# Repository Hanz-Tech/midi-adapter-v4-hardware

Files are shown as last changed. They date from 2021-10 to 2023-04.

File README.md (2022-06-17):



Buy it Here 

<a href="https://hanztechnology.com/shop">https://hanztechnology.com/shop</a>

OR



# Disclaimer

You are free to:

Share — copy and redistribute the material in any medium or format

Adapt — remix, transform, and build upon the material

________________________________________

Attribution — You must give appropriate credit, provide a link to the license, and indicate if changes were made. You may do so in any reasonable manner, but not in any way that suggests the licensor endorses you or your use.

NonCommercial — You may not use the material for commercial purposes.

___________________________________________

THE HARDWARE IS PROVIDED "AS IS", WITHOUT WARRANTY OF ANY KIND, EXPRESS OR IMPLIED, INCLUDING BUT NOT LIMITED TO THE WARRANTIES OF MERCHANTABILITY, FITNESS FOR A PARTICULAR PURPOSE AND NONINFRINGEMENT. IN NO EVENT SHALL THE AUTHORS OR COPYRIGHT HOLDERS BE LIABLE FOR ANY CLAIM, DAMAGES OR OTHER LIABILITY, WHETHER IN AN ACTION OF CONTRACT, TORT OR OTHERWISE, ARISING FROM, OUT OF OR IN CONNECTION WITH THE HARDWARE OR THE USE OR OTHER DEALINGS IN THE HARDWARE.

_____________________________________________

# Overview

This repo contains both the CAD for the 3D printed cover for the Pocket Operator and the PCB schematic for the adapter. PCB is created using KiCad. Software can be found [here](https://github.com/PO-MIDI-Adapter/midi-adapter-software/tree/v2)

## For assmebly instruction please go to the [wiki](https://github.com/PO-MIDI-Adapter/midi-adapter-hardware/wiki)

PO-MA (https://www.youtube.com/watch?v=n_peiBfl6JI "PO-MA")

# Photos

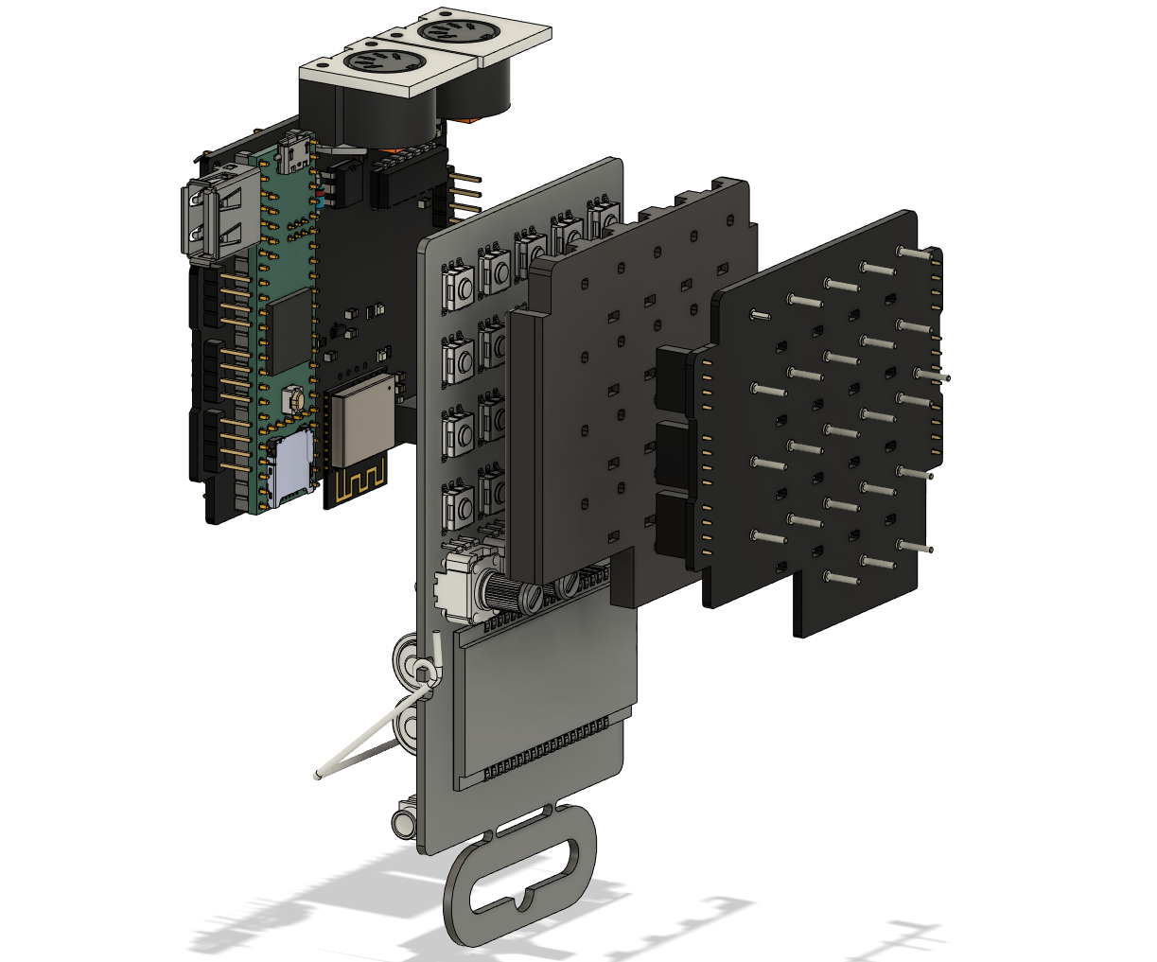
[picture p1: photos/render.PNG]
Render







# BOM
<!-- 
1. 1 x PCB board
2. 1 x 3D printed cover (Found in the cad folder)
3. 2 x cover holders  (Found in the cad folder)
4. 25 x pogo pins [ebay](https://www.ebay.ca/itm/100pcs-9mm-Length-Spring-Loaded-Test-Probes-Pogo-Pins-Cusp-Spear-for-Testing/163156710143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)
5. 1 x PJ320B 3.5MM Audio Jack (ebay)

In addition, you would need the following electronics from Digikey (bom.csv)

|Manufacturer Part Number|Manufacturer |Digi-Key Part Number|Quantity|Description |Placement|
|---|---|---|---|---|---|
|SN74HC125N |Texas Instruments |296-1572-5-ND |1 |IC BUFFER NON-INVERT 6V 14DIP |U2
|A 14-LC-TT |Assmann WSW Components |AE9989-ND |1 |CONN IC DIP SOCKET 14POS TIN |U2
|1-2199298-1 |TE Connectivity |A120346-ND |1 |CONN IC DIP SOCKET 6POS TIN |U3
|H11L1M |ON Semiconductors |H11L1-MQT-ND |1 |OPTOISO 4.17KV OPN COLL 6DIP |U3
|PRPC028SACN-RC |Sullins Connector Solutions|S1131EC-28-ND |2 |CONN HEADER VERT 28POS 2.54MM |U1
|DEV-16771 |SparkFun Electronics |1568-DEV-16771-ND |1 |TEENSY 4.1 W/OUT HDRS K66 EVAL  |U1
|SDS-50J |CUI Inc. |CP-2350-ND |2 |CONN RCPT FMALE DIN 5POS SOLDER |J29,J30
|CF14JT220R |Stackpole Electronics Inc  |CF14JT220RCT-ND |3 |RES 220 OHM 1/4W 5% AXIAL |R2,R3,R7
|CF14JT10K0 |Stackpole Electronics Inc  |CF14JT10K0CT-ND |1 |RES 10K OHM 1/4W 5% AXIAL |R4
|CF14JT470R |Stackpole Electronics Inc  |CF14JT470RTR-ND |1 |RES 470 OHM 1/4W 5% AXIAL |R8
|USB-A1HSW6 |On Shore Technology Incs |ED2989-ND |1 |USB-A Receptacle Connector 4 Pos|J19
|C315C104M5U5TA7303 |KEMET |399-9859-1-ND |2 |CAP CER 0.1UF 50V Z5U RADIAL |C2,C1
|PPTC041LFBN-RC |Sullins Connector Solutions|S7002-ND |1 |CONN HDR 4POS 0.1 TIN PCB |J32
|1N914 |ON Semiconductor |1N914FS-ND |1 |DIODE GEN PURP 100V 200MA DO35  |D1

Optional

|Manufacturer Part Number|Manufacturer |Digi-Key Part Number|Quantity  |Description |Placement|
|---|---|---|---|---|---|
|PPTC241LFBN-RC |Sullins Connector Solutions|S7022-ND |2 |CONN HDR 24POS 0.1 TIN PCB |U1 -->

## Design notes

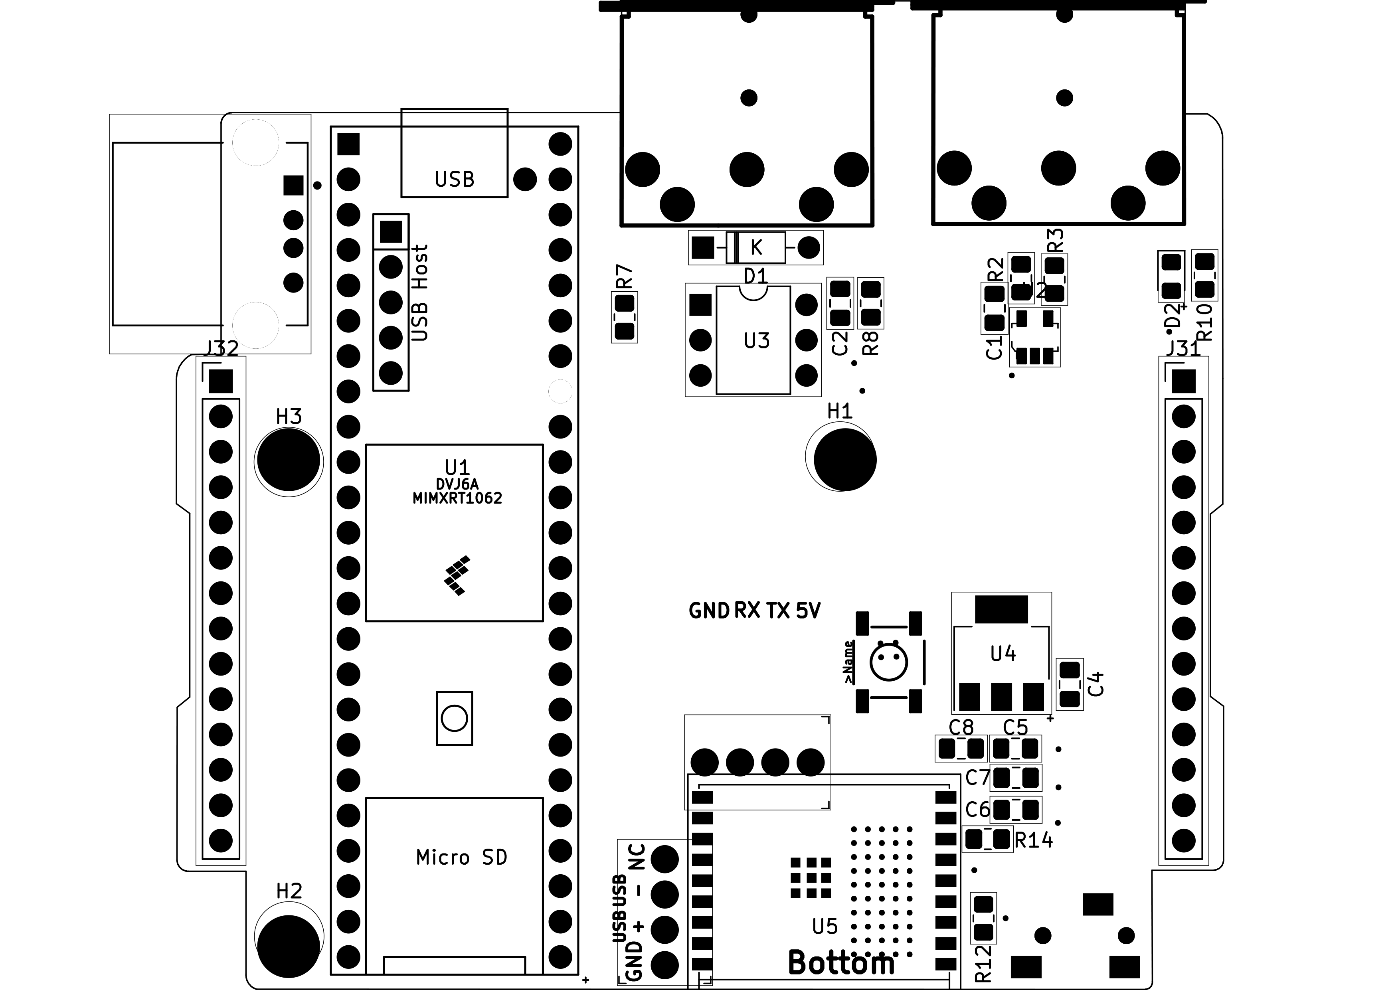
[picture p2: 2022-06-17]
pcb/kicad/export/bottom/pritnt.png

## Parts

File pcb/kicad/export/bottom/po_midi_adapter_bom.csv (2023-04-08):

Comment | Designator | Footprint | LCSC
0.1uF | C1,C2,C6,C8 | Capacitor_SMD:C_0805_2012Metric_Pad1.18x1.45mm_HandSolder | C28233
10uF | C15,C20,C23,C32,C34,C36 | Capacitor_SMD:C_0402_1005Metric | C105884
1uF | C16,C17,C26,C27,C30,C31 | Capacitor_SMD:C_0402_1005Metric | C326568
47uF | C18,C19,C28,C29 | Capacitor_SMD:C_0805_2012Metric | C16780
0.1uF | C21,C22,C24,C25,C33,C35,C37,C38 | Capacitor_SMD:C_0402_1005Metric | C49678
10uF | C7 | Capacitor_SMD:C_0805_2012Metric_Pad1.18x1.45mm_HandSolder | C440198
2.2uF | C9,C10,C11,C12 | Capacitor_SMD:C_0402_1005Metric | C12503
1N4148 | D1 | poma:SOD-123 | C908248
LED | D2 | LED_SMD:LED_0805_2012Metric_Pad1.15x1.40mm_HandSolder | C401117
PJ-320B | J1,J2,J81,J82 | jacks:3.5mm_stereo_jack_PJ320B | C707224
Conn_01x14_Female | J31,J32 | Connector_PinHeader_2.54mm:PinHeader_1x14_P2.54mm_Vertical | C124407
PJ-320B | J83,J84 | poma:3.5mm_stereo_jack_PJ320B | C707224
68 | R10 | Resistor_SMD:R_0805_2012Metric_Pad1.20x1.40mm_HandSolder | C17784
10K | R12,R14 | Resistor_SMD:R_0805_2012Metric_Pad1.20x1.40mm_HandSolder | C17414
33R | R15,R16,R17,R18,R19,R20,R21 | Resistor_SMD:R_0402_1005Metric | C25105
220 | R2,R3,R7 | Resistor_SMD:R_0805_2012Metric_Pad1.20x1.40mm_HandSolder | C17557
6.8K | R22,R23 | Resistor_SMD:R_0402_1005Metric | C25917
10K | R24,R25 | Resistor_SMD:R_0402_1005Metric | C25744
100 | R26,R27 | Resistor_SMD:R_0402_1005Metric | C25076
470 | R8 | Resistor_SMD:R_0805_2012Metric_Pad1.20x1.40mm_HandSolder | C17710
R_Potentiometer_US | RV1,RV2,RV3 | poma:RES-ADJ-TH_RK09Y11L0001 | C470717
SN74LVC1G07DBVR | U2 | digikey-footprints:SOT-753 | C7829
H11L1S | U3 | poma:IC_H11L1SM | C78589
ESP32-C3-WROOM-02 | U5 | Espressif:ESP32-C3-WROOM-02 | C2934560
LP5907MFX-3.3 | U6 | Package_TO_SOT_SMD:SOT-23-5 | C80670
LP5907MFX-1.8 | U7 | Package_TO_SOT_SMD:SOT-23-5 | C92498
SN74LV4052APWE4 | U8 | poma:SN74LV4052APWE4 | C8142
TLV320AIC3204IRHBR | UNK1 | Package_DFN_QFN:QFN-32-1EP_5x5mm_P0.5mm_EP3.45x3.45mm | C24109

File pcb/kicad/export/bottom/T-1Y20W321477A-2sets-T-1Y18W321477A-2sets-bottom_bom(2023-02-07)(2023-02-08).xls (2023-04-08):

PCBWay Bom Quotation, Product No.:T-1Y20W321477A
Item # | *Designator | *Qty | Manufacturer | *Mfg Part # | Description / Value | *Package/Footprint | *Unit Price(2 sets) | *Total | *Actual Purchase Mfg Part # | Customer Reply
1 | C1,C2,C6,C8 | 4 | YAGEO | 0.1uF | 0.1uF | Capacitor_SMD:C_0805_2012Metric_Pad1.18x1.45mm_HandSolder | $0.116 | $0.928 | CC0805KRX7R9BB104
2 | C15,C23,C32,C34,C36 | 5 | YAGEO | 10uF | 10uF | Capacitor_SMD:C_0402_1005Metric | $0.092 | $0.920 | CC0402MRX5R5BB106
3 | C16,C17,C26,C27,C30,C31 | 6 | YAGEO | 1uF | 1uF | Capacitor_SMD:C_0402_1005Metric | $0.096 | $1.152 | CC0402KRX5R8BB105
4 | C18,C19,C28,C29 | 4 | muRata | 47uF | 47uF | SMD 0603_1608 | $0.233 | $1.864 | GRM188R60J476ME15D
5 | C20,C21,C22,C24,C25,C33,C35,C37,C38 | 9 | YAGEO | 0.1uF | 0.1uF | Capacitor_SMD:C_0402_1005Metric | $0.045 | $0.810 | CC0402KRX7R9BB104
6 | C7 | 1 | YAGEO | 10uF | 10uF | Capacitor_SMD:C_0805_2012Metric_Pad1.18x1.45mm_HandSolder | $0.277 | $0.554 | CC0805KKX5R6BB106
7 | C9,C10,C11,C12 | 4 | YAGEO | 2.2uF | 2.2uF | Capacitor_SMD:C_0402_1005Metric | $0.117 | $0.936 | CC0402KRX5R6BB225
8 | D1 | 1 | CJ | 1N4148 | 1N4148 | SOD-123 | $0.363 | $0.726 | 1N4148W
9 | D2 | 1 | Wurth Elektronik | 150080YS75000 | LED | LED_SMD:LED_0805_2012Metric_Pad1.15x1.40mm_HandSolder | $0.816 | $1.632
10 | J1,J2,J81,J82 | 4 | 韩国韩荣 | PJ-320B | PJ-320B | SMD | $0.178 | $1.424 | PJ-320B-3A
11 | J83,J84 | 2 | 韩国韩荣 | PJ-320B | PJ-320B | SMD | $0.178 | $0.712 | PJ-320B-3A
12 | R10 | 1 | YAGEO | 50 | 50 | Resistor_SMD:R_0805_2012Metric_Pad1.20x1.40mm_HandSolder | $0.173 | $0.346 | RC0805FR-0749R9L
13 | R12,R14 | 2 | YAGEO | 10K | 10K | Resistor_SMD:R_0805_2012Metric_Pad1.20x1.40mm_HandSolder | $0.087 | $0.348 | RC0805FR-0710KL
14 | R15,R16,R17,R18,R19,R20,R21 | 7 | YAGEO | 33R | 33R | Resistor_SMD:R_0402_1005Metric | $0.050 | $0.700 | RC0402FR-0733RL
15 | R2,R3,R7 | 3 | YAGEO | 220 | 220 | Resistor_SMD:R_0805_2012Metric_Pad1.20x1.40mm_HandSolder | $0.058 | $0.348 | RC0805FR-07220RL
16 | R22,R23 | 2 | YAGEO | 6K | 6K | Resistor_SMD:R_0402_1005Metric | $0.079 | $0.316 | RC0402FR-075K9L
17 | R24,R25 | 2 | YAGEO | 10K | 10K | Resistor_SMD:R_0402_1005Metric | $0.087 | $0.348 | RC0402FR-0710KL
18 | R26,R27 | 2 | YAGEO | 100 | 100 | Resistor_SMD:R_0402_1005Metric | $0.087 | $0.348 | RC0402FR-07100RL
19 | R8 | 1 | YAGEO | 470 | 470 | Resistor_SMD:R_0805_2012Metric_Pad1.20x1.40mm_HandSolder | $0.173 | $0.346 | RC0805FR-07470RL
20 | U2 | 1 | Texas Instruments | SN74LVC1G07DBVR | SN74LVC1G07DBVR | SOT-753 | $0.295 | $0.590
21 | U3 | 1 | onsemi | H11L1S | H11L1S | SMD-6 | $1.016 | $2.032 | H11L1SR2M
22 | U6 | 1 | Texas Instruments | LP5907MFX-3.3 | LP5907MFX-3.3 | Package_TO_SOT_SMD:SOT-23-5 | $0.664 | $1.328 | LP5907MFX-3.3/NOPB
23 | U7 | 1 | Texas Instruments | LP5907MFX-1.8 | LP5907MFX-1.8 | Package_TO_SOT_SMD:SOT-23-5 | $0.822 | $1.644 | LP5907MFX-1.8/NOPB
24 | U8 | 1 | Texas Instruments | SN74LV4052APWR | SN74LV4052APWR | TSSOP-16 | $0.664 | $1.328
25 | UNK1 | 1 | Texas Instruments | TLV320AIC3204IRHBR | TLV320AIC3204IRHBR | QFN-32-EP(5x5) | $2.695 | $5.390
26 | J31,J32 | 2 | Ckmtw | B-2200S14P-A120 | B-2200S14P-A120 | 14 Pin Female Header 2.54mm | $0.405 | $1.620
 |  |  |  |  |  |  | All Total | $28.690

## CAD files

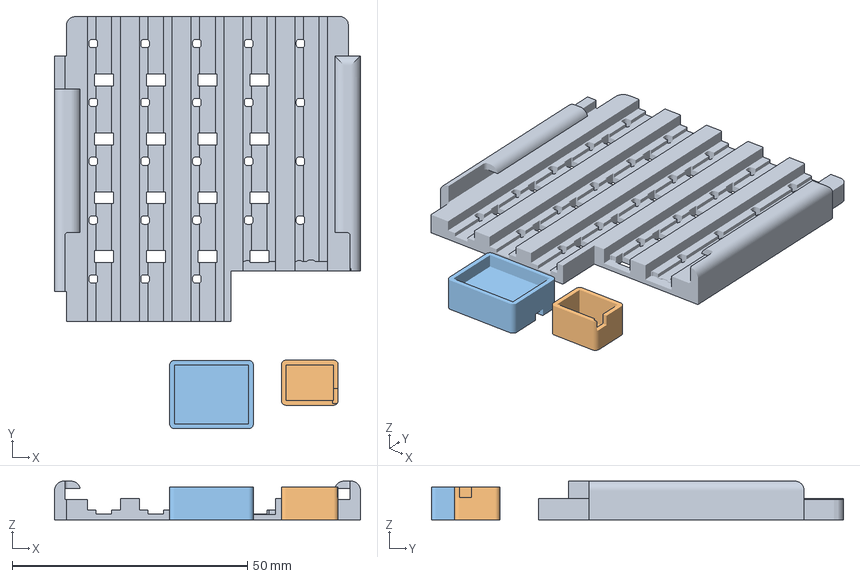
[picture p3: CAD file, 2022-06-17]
cad/stl/cover/1set_complete.3mf
65.0 x 87.6 x 8.25 mm
cover
optoisolator_cover
esp32_cover

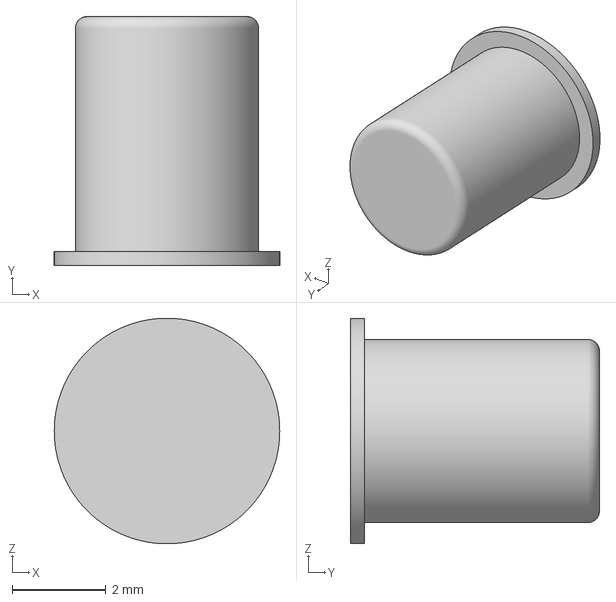
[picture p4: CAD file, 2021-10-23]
cad/f3d/cover/button.3mf
4.80 x 5.30 x 4.80 mm

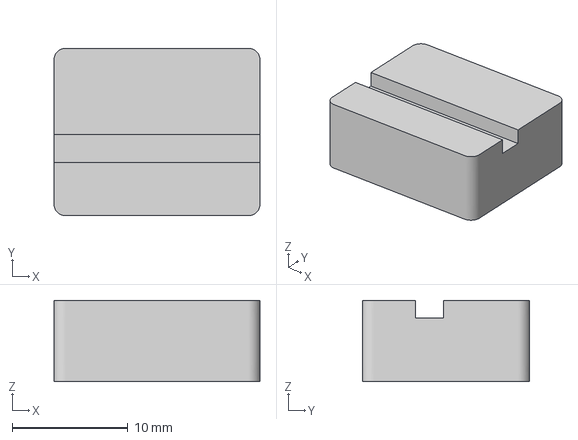
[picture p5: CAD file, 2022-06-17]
cad/stl/cover/esp32_cover.3mf
17.8 x 14.5 x 7.00 mm

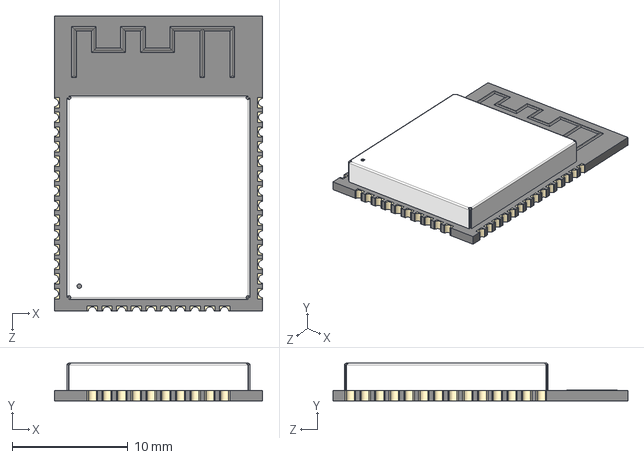
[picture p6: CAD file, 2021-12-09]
pcb/kicad/ESP32-WROOM-32D/ESP32-WROOM-32D.step
18.0 x 3.25 x 25.5 mm

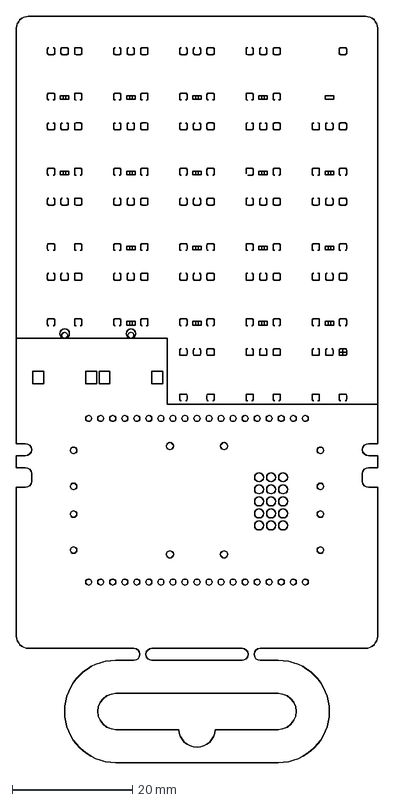
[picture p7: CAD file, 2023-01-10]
pcb/kicad/PO CAD_empty v1.dxf
60.0 x 124.0 mm

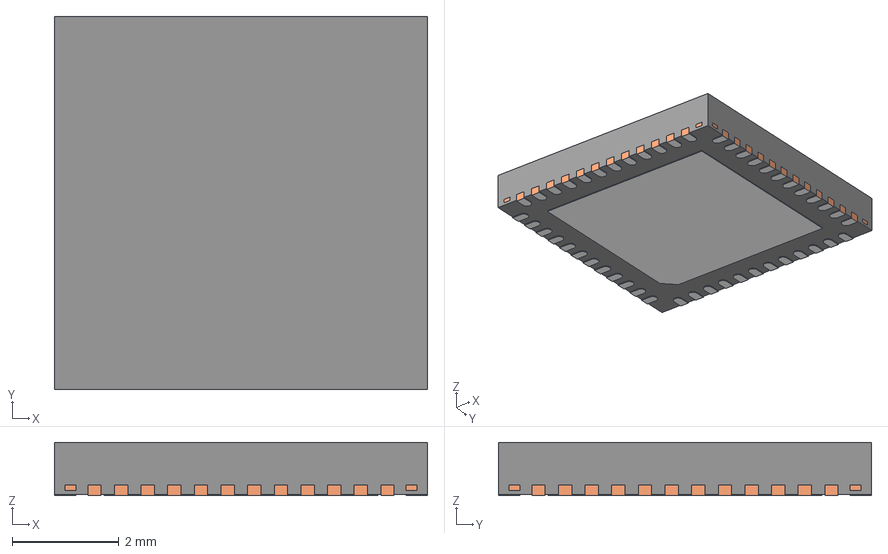
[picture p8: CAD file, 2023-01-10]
pcb/kicad/step/tlv.stp
7.00 x 7.00 x 1.00 mm
BODY-QFN
FRAME-RGZ0048A
PIN1-ID

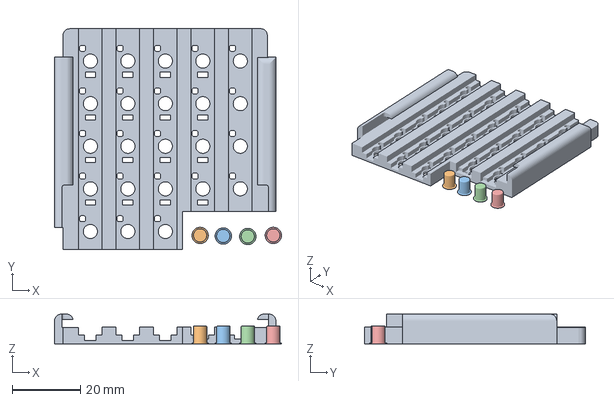
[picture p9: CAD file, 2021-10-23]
cad/f3d/cover/cover.3mf
66.6 x 64.8 x 8.75 mm

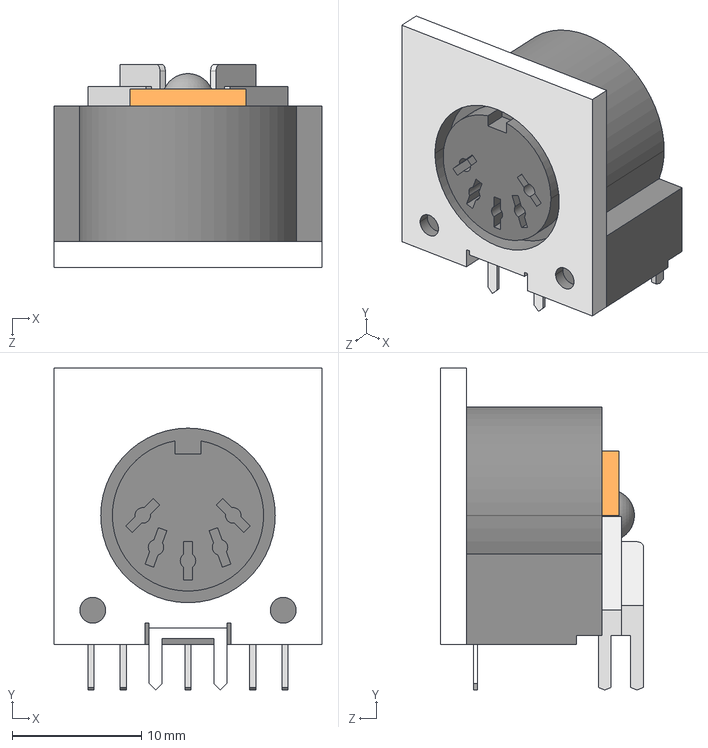
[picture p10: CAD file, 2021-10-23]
pcb/kicad/step/CUI_DEVICES_SDF-50J.step
20.7 x 24.9 x 15.7 mm

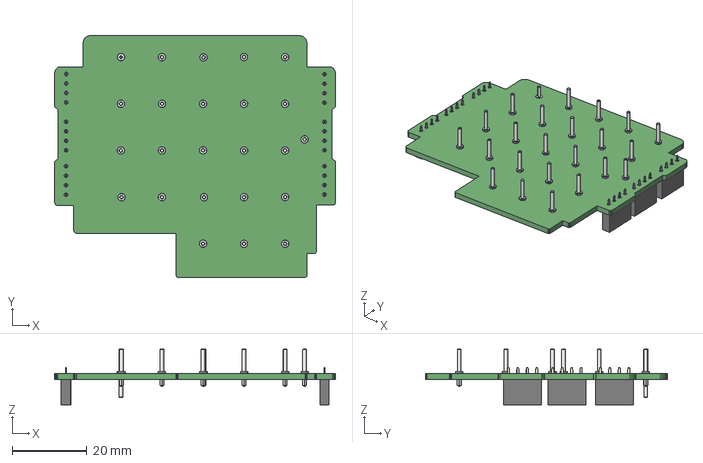
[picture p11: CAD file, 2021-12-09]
pcb/kicad/top.step
75.3 x 64.8 x 15.0 mm

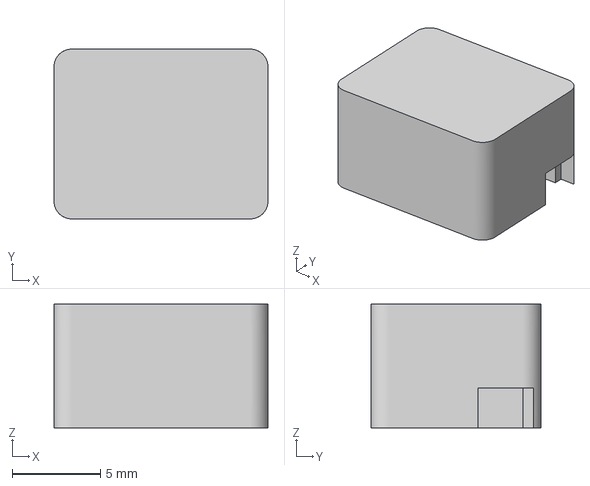
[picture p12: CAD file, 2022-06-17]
cad/stl/cover/optoisolator_cover.3mf
12.1 x 9.60 x 7.00 mm

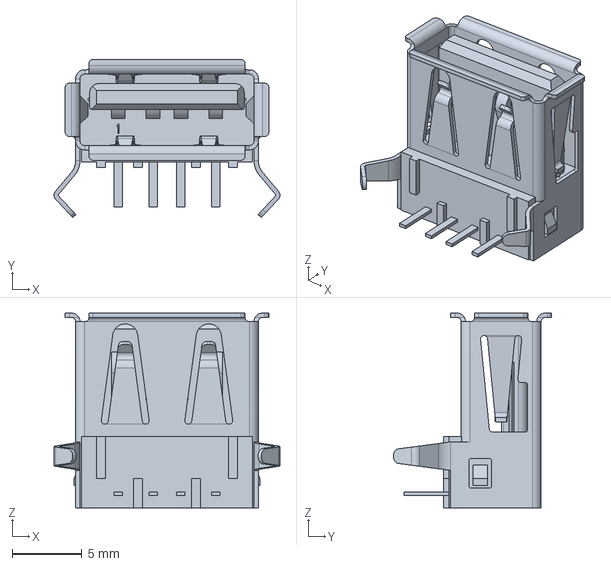
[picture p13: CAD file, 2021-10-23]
pcb/kicad/step/c-292303-1-e4-3d.stp
16.2 x 11.4 x 14.0 mm

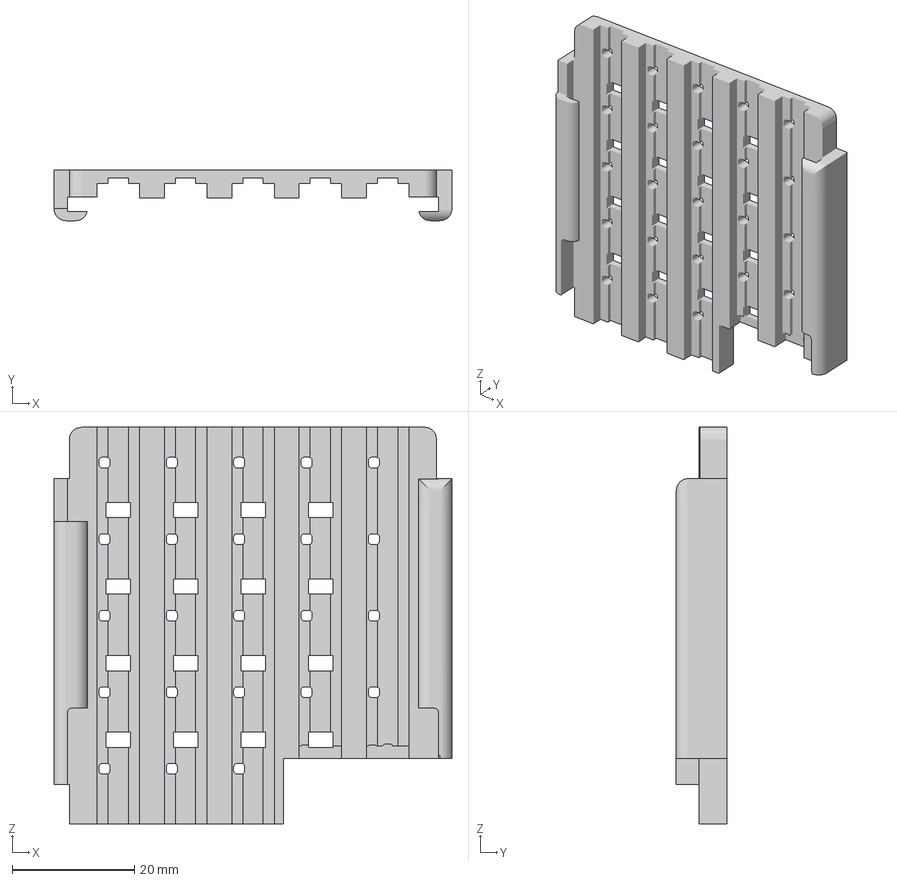
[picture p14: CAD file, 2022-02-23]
cad/stl/cover/cover.3mf
65.0 x 8.25 x 64.8 mm

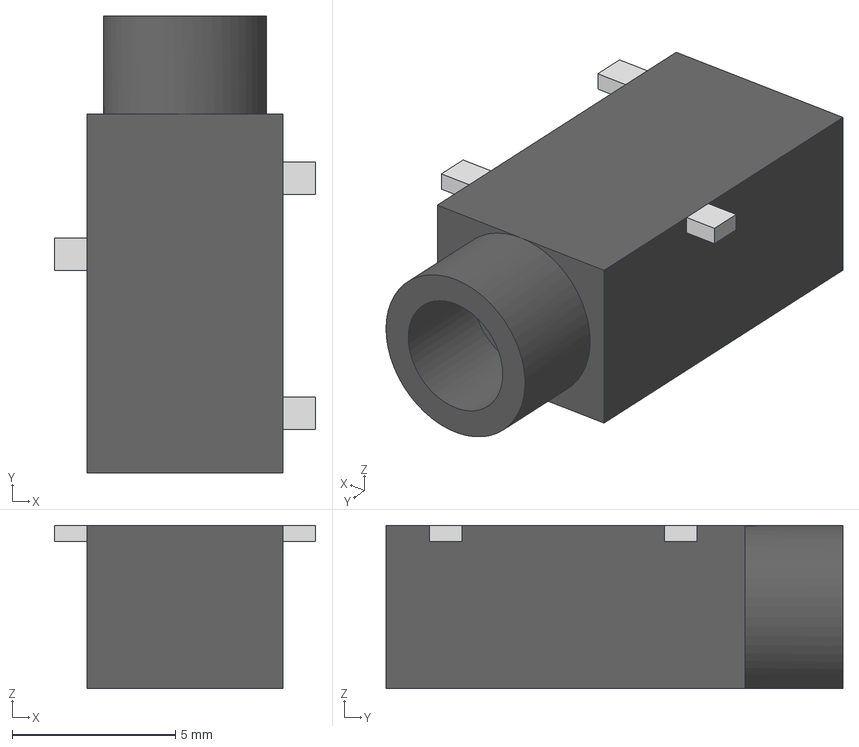
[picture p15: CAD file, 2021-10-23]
pcb/kicad/step/audio_jack v2.step
8.00 x 14.0 x 5.00 mm

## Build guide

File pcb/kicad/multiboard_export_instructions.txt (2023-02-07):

kikit separate --source 'rectangle; tlx: 25.374mm; tly: 45.56mm; brx: 115.07mm; bry: 122.86mm' ./po_midi_adapter.kicad_pcb top.kicad_pcb

kikit separate --source 'rectangle; tlx: 115.37mm; tly: 30.6mm; brx: 206.474mm; bry: 125.56mm' ./po_midi_adapter.kicad_pcb bottom.kicad_pcb

kikit stencil create  --jigsize 100 100 bottom.kicad_pcb export

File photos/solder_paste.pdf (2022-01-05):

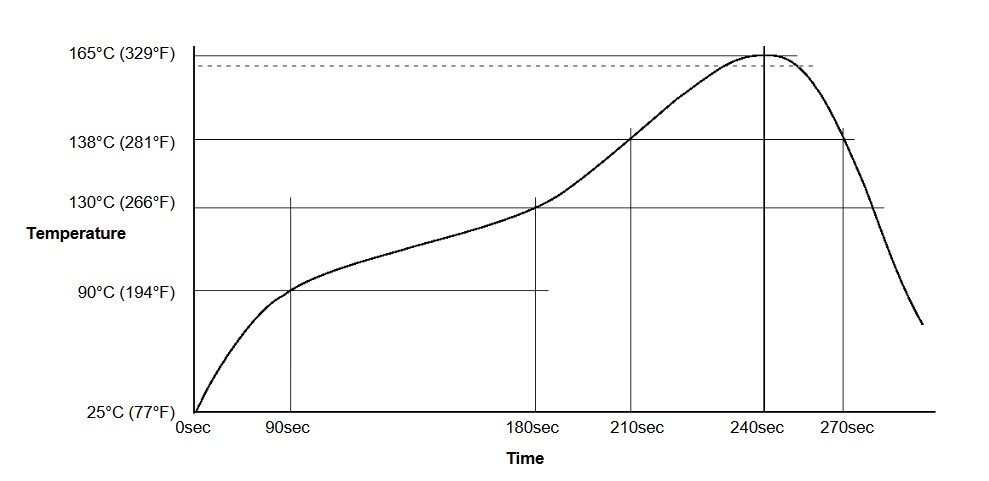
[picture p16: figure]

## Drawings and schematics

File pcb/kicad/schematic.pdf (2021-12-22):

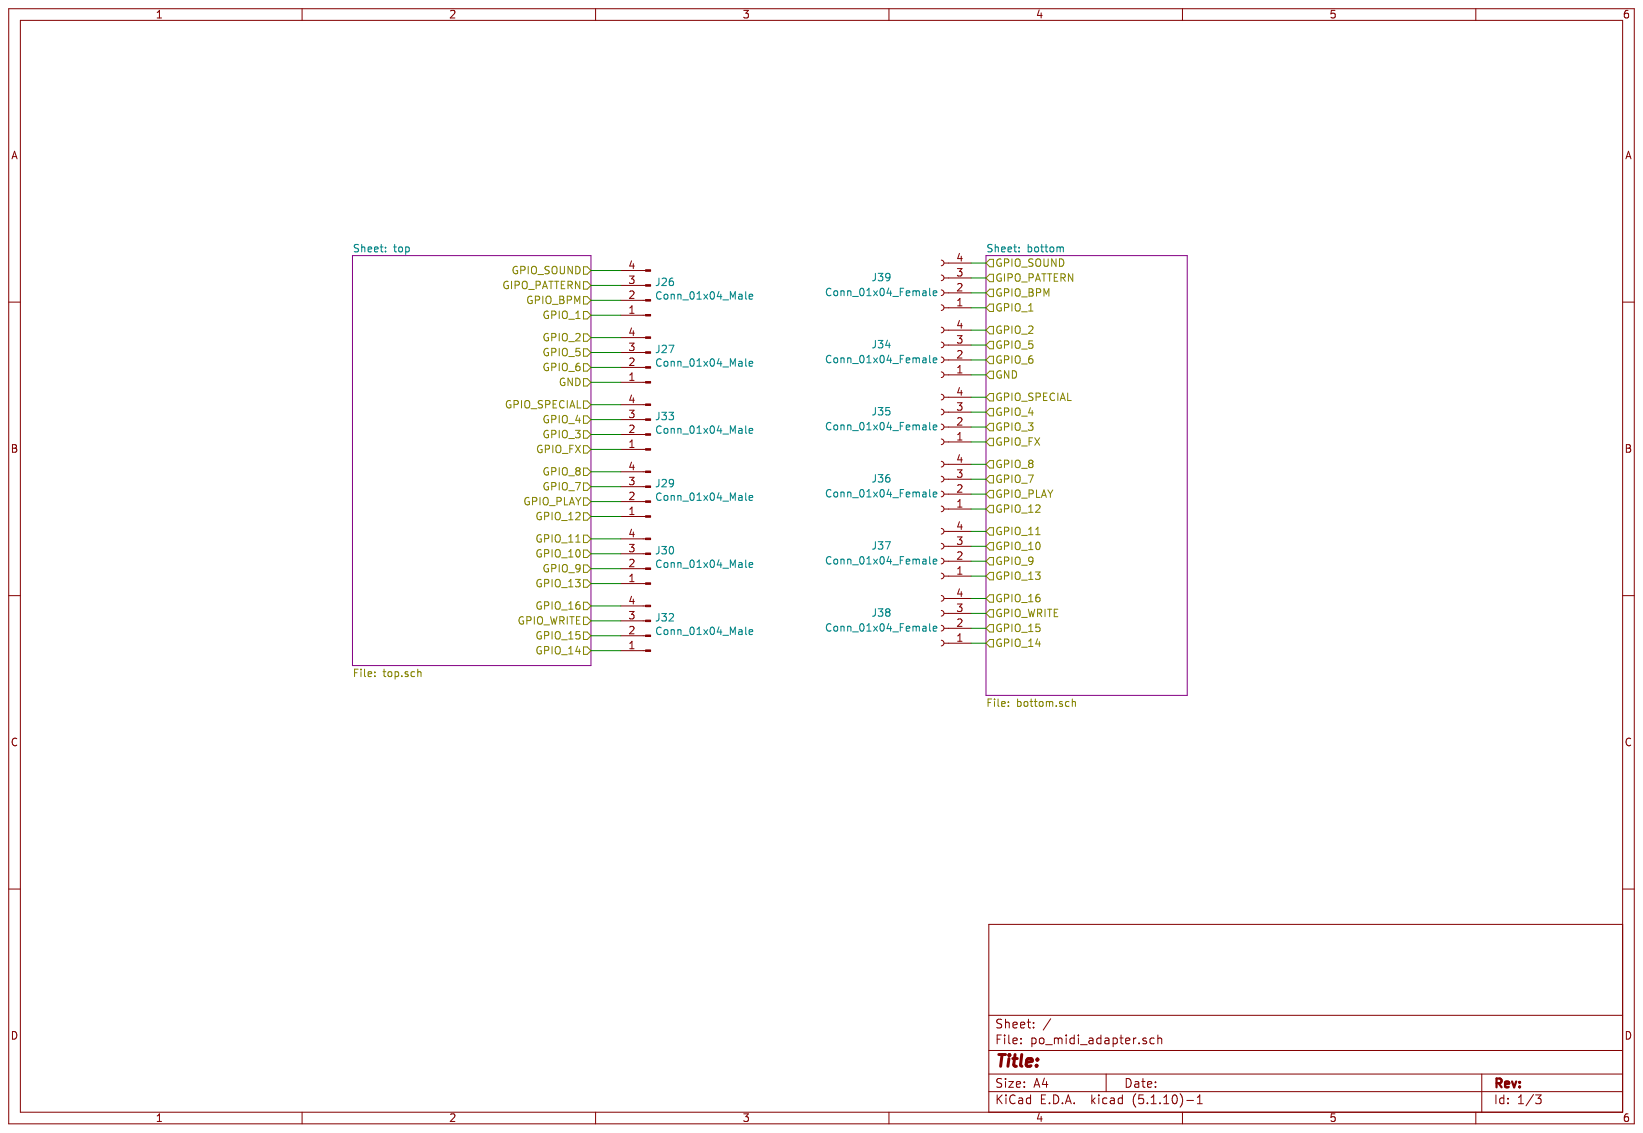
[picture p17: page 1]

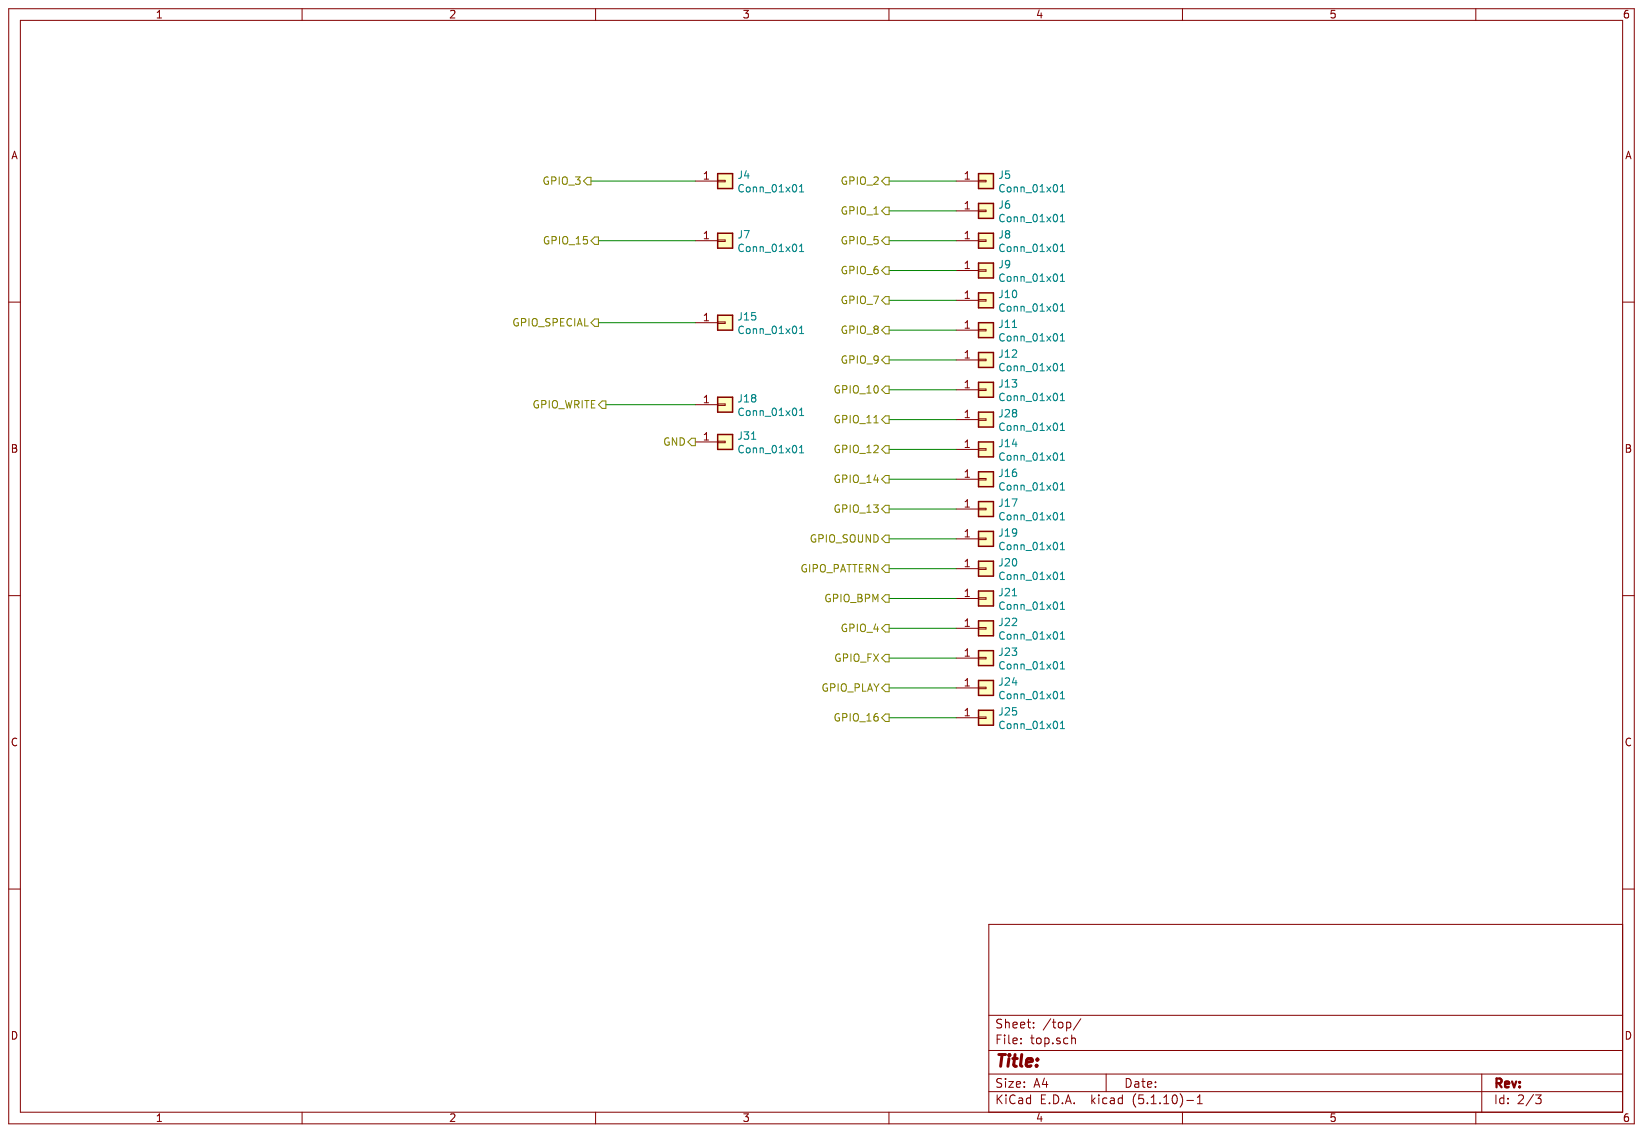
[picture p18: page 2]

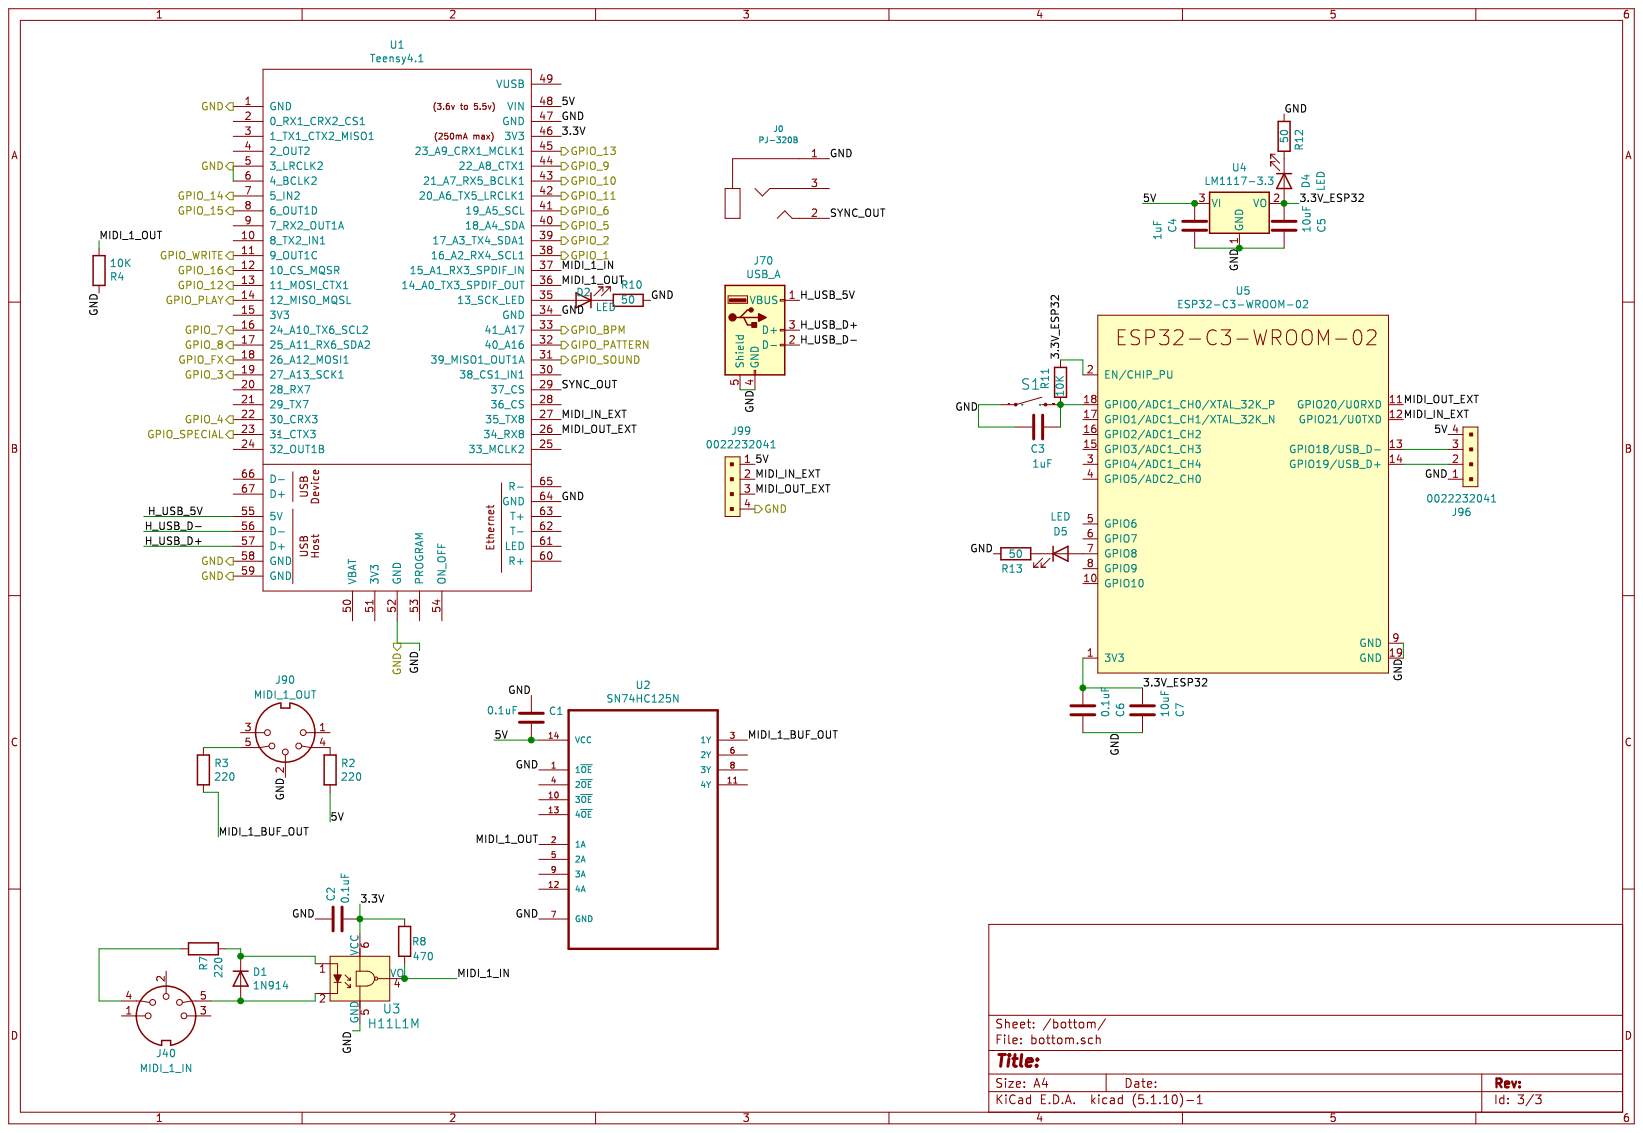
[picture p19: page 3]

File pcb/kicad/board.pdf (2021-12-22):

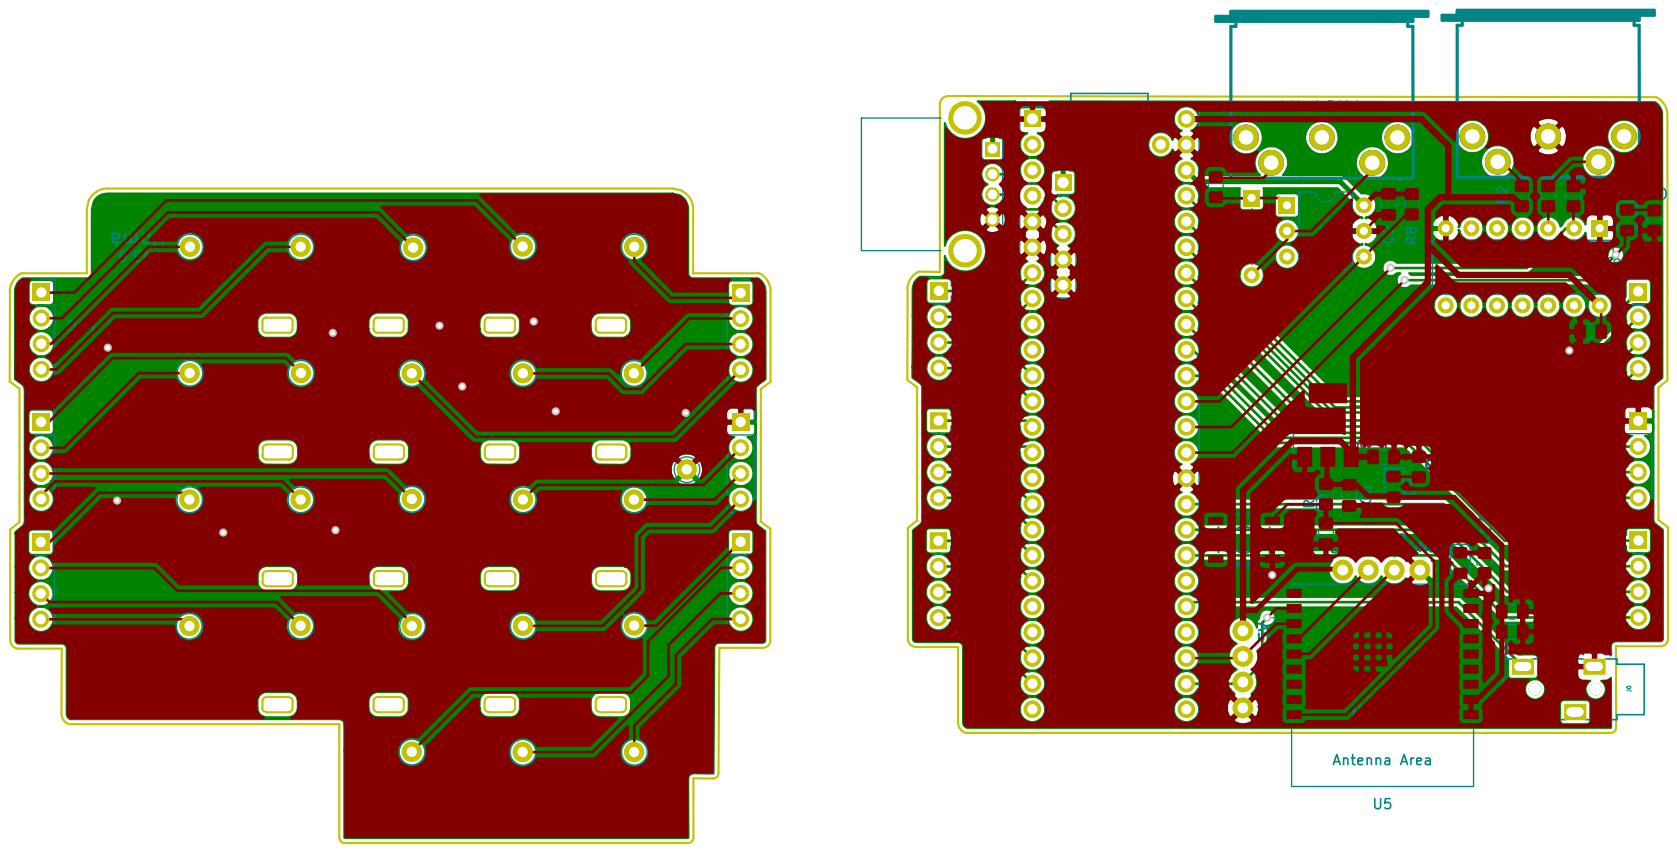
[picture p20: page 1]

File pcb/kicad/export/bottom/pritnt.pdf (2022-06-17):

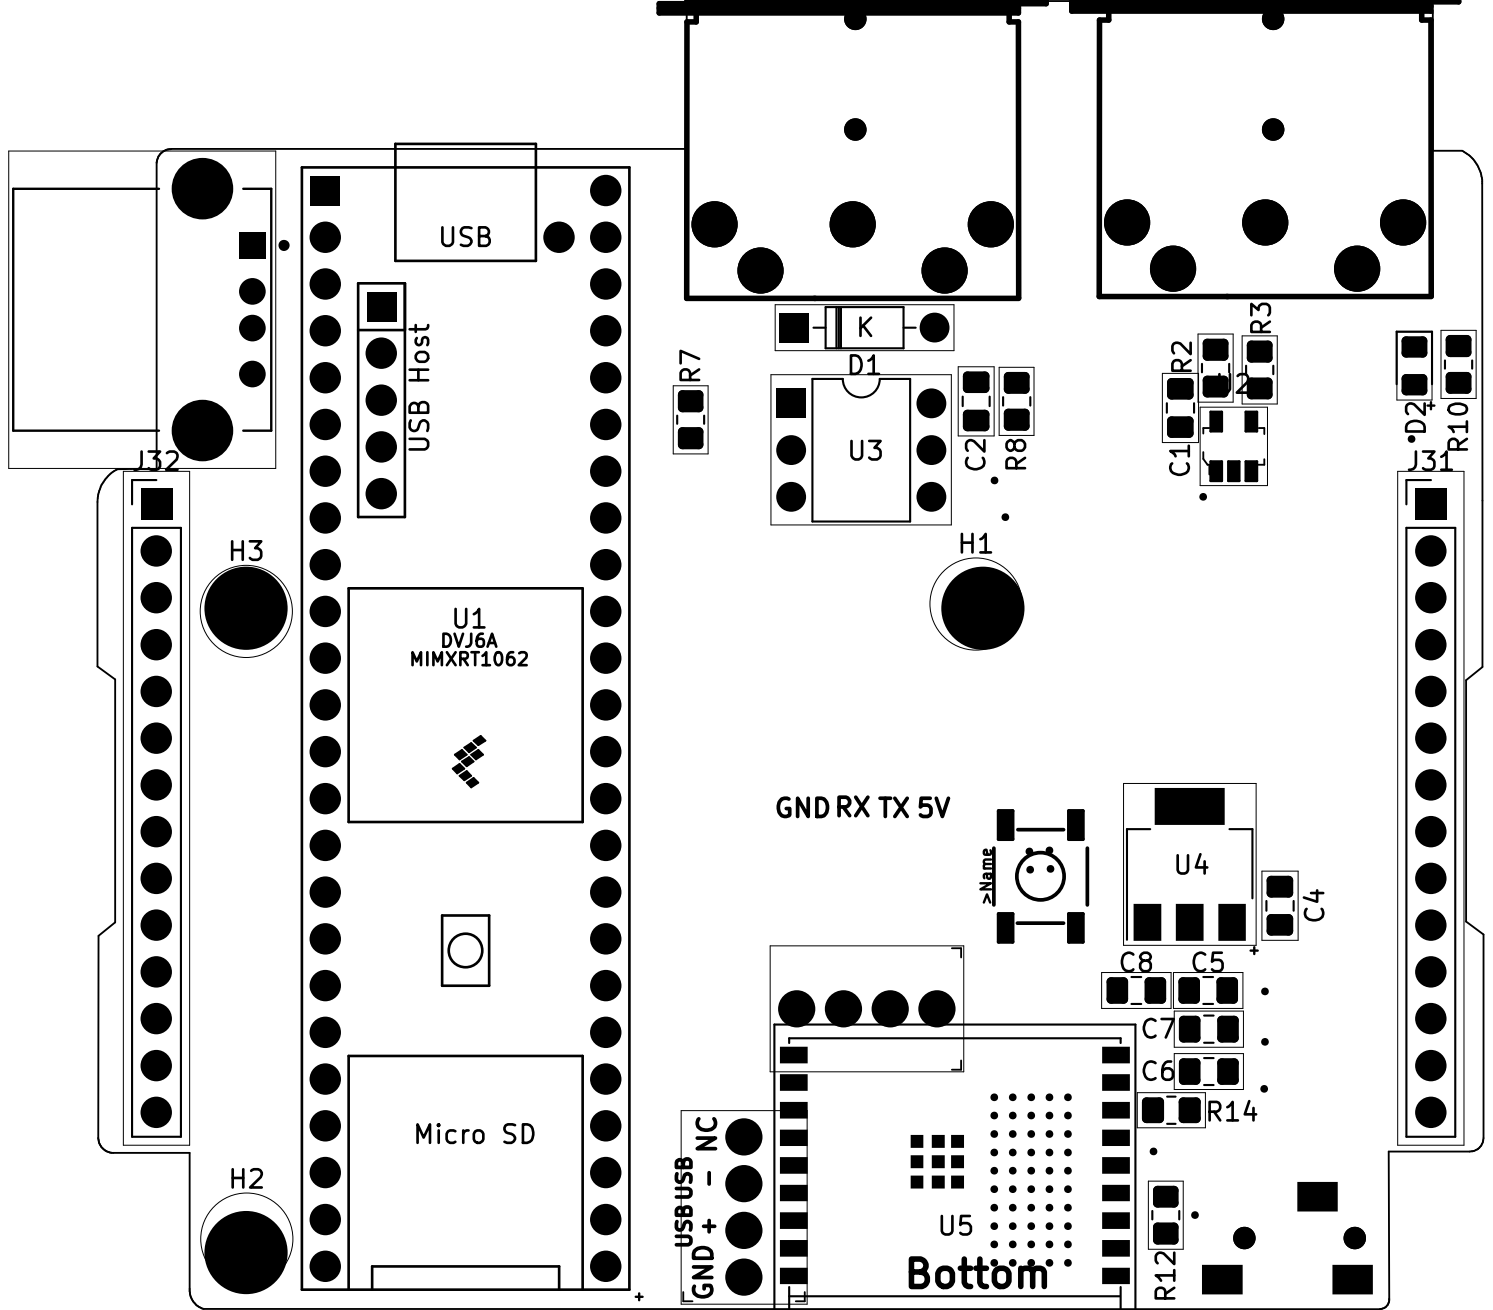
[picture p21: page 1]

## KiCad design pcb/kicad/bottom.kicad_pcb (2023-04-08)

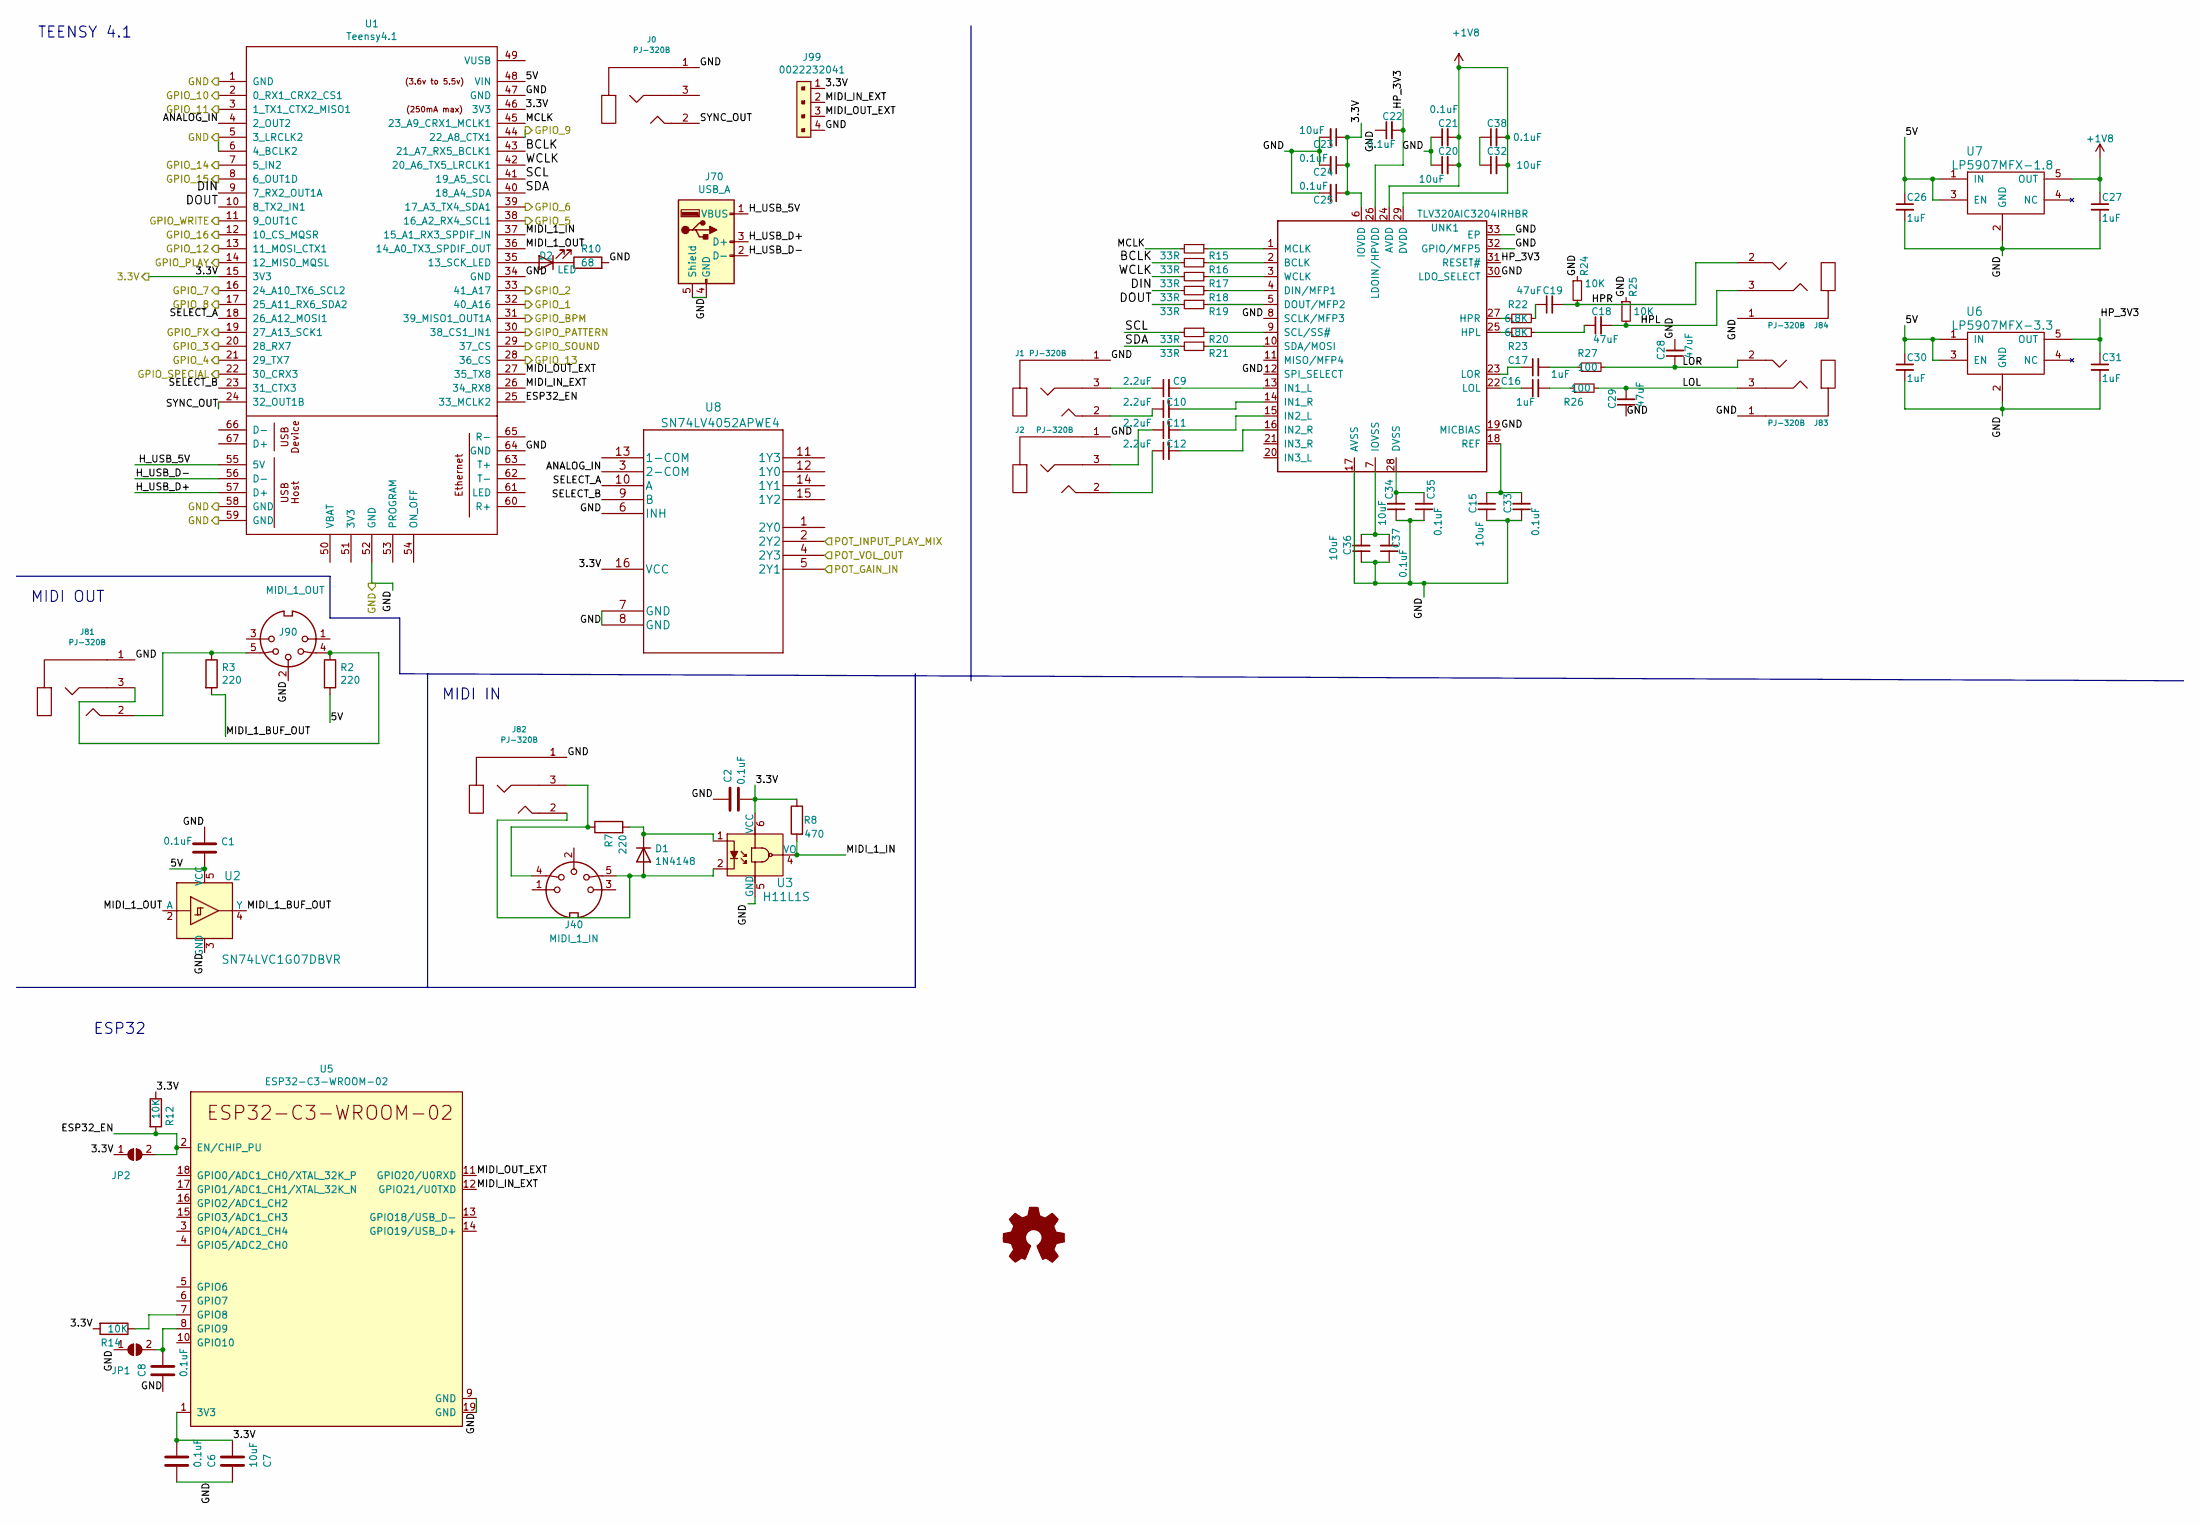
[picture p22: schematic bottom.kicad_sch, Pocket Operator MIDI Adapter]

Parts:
C1, C2, C6, C8: 0.1uF; C_0805_2012Metric_Pad1.18x1.45mm_HandSolder; LCSC C28233
C7: 10uF; C_0805_2012Metric_Pad1.18x1.45mm_HandSolder; LCSC C440198
C9, C10, C11, C12: 2.2uF; C_0402_1005Metric; MPN C326606; LCSC C12530
C15, C20, C23, C32, C34, C36: 10uF; C_0402_1005Metric; LCSC C15525
C16, C17, C26, C27, C30, C31: 1uF; C_0402_1005Metric; MPN C326568; LCSC C28233
C18, C19, C28, C29: 47uF; C_0805_2012Metric; LCSC C16780
C21, C22, C24, C25, C33, C35, C37, C38: 0.1uF; C_0402_1005Metric; MPN C49678; LCSC C1525
D1: 1N4148; D_SOD-123; LCSC C81598
D2: LED; LED_0805_2012Metric_Pad1.15x1.40mm_HandSolder; LCSC C2296
J0: PJ-320B; 3.5mm_stereo_jack_PJ320B_THRU
J1, J2, J81, J82, J83, J84: PJ-320B; 3.5mm_stereo_jack_PJ320B; LCSC C707224
J40: MIDI_1_IN; MIDI_DIN5_NO_ATTACHEMENT
J70: USB_A; TE_292303-1; LCSC C86461
J90: MIDI_1_OUT; MIDI_DIN5_NO_ATTACHEMENT
J99: 0022232041; PinHeader_1x4_P2.54mm_Drill1.02mm; MPN 0022232041; Digi-Key_PN WM4202-ND
JP1, JP2: Jumper; SolderJumper-2_P1.3mm_Open_Pad1.0x1.5mm
R2, R3, R7: 220; R_0805_2012Metric_Pad1.20x1.40mm_HandSolder; LCSC C17557
R8: 470; R_0805_2012Metric_Pad1.20x1.40mm_HandSolder; LCSC C17710
R10: 68; R_0805_2012Metric_Pad1.20x1.40mm_HandSolder; LCSC C17802
R12, R14: 10K; R_0805_2012Metric_Pad1.20x1.40mm_HandSolder; LCSC C17414
R15, R16, R17, R18, R19, R20, R21: 33R; R_0402_1005Metric; LCSC C25105
R22, R23: 6.8K; R_0402_1005Metric; LCSC C25917
R24, R25: 10K; R_0402_1005Metric; LCSC C25744
R26, R27: 100; R_0402_1005Metric; LCSC C25076
U1: Teensy4.1; Teensy41_poma
U2: SN74LVC1G07DBVR; SOT-753; MPN SN74LVC1G07DBVR; Digi-Key_PN 296-8485-1-ND
U3: H11L1S; IC_H11L1SM; MPN H11L1S; Digi-Key_PN H11L1-MQT-ND
U5: ESP32-C3-WROOM-02; MPN ESP32-C3-WROOM-02; LCSC C2934560
U6: LP5907MFX-3.3; SOT-23-5; MPN LP5907MFX-3.3; LCSC C80670
U7: LP5907MFX-1.8; SOT-23-5; MPN LP5907MFX-1.8; LCSC C92498
U8: SN74LV4052APWE4; MPN SN74LV4052APWR; LCSC C8142
UNK1: TLV320AIC3204IRHBR; QFN-32-1EP_5x5mm_P0.5mm_EP3.45x3.45mm; MPN TLV320AIC3204IRHBR; LCSC C24109

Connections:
Board_0-+1V8: C20.2, C21.2, C27.1, C32.2, C38.2, U7.5 (OUT), UNK1.24 (AVDD), UNK1.29 (DVDD)
Board_0-/bottom/3.3V: C2.2, C6.1, C7.1, C23.1, C24.1, C25.1, J99.1, JP2.1 (A), R8.1, R12.1, R14.2, U1.15 (3V3), U1.46 (3V3), U3.6 (VCC), U5.1 (3V3), U8.16 (VCC), UNK1.6 (IOVDD); also elsewhere on the board
Board_0-/bottom/5V: C1.2, C26.1, C30.1, R2.2, U1.48 (VIN), U2.5 (VCC), U6.1 (IN), U6.3 (EN), U7.1 (IN), U7.3 (EN)
Board_0-/bottom/ANALOG_IN: U1.4 (2_OUT2), U8.3 (2-COM)
Board_0-/bottom/BCLK: R16.2, U1.43 (21_A7_RX5_BCLK1)
Board_0-/bottom/DIN: R18.2, U1.9 (7_RX2_OUT1A)
Board_0-/bottom/DOUT: R19.2, U1.10 (8_TX2_IN1)
Board_0-/bottom/ESP32_EN: JP2.2 (B), R12.2, U1.25 (33_MCLK2), U5.2 (EN/CHIP_PU)
Board_0-/bottom/GIPO_PATTERN: U1.30 (38_CS1_IN1); also elsewhere on the board
Board_0-/bottom/GND: C1.1, C2.1, C6.2, C7.2, C8.2, C15.1, C20.1, C21.1, C22.1, C23.2, C24.2, C25.2, C26.2, C27.2, C28.2, C29.1, C30.2, C31.2, C33.1, C34.1, C35.1, C36.1, C37.1, J0.1, J1.1, J2.1, J70.4 (GND), J70.5 (Shield), J81.1, J82.1, J83.1, J84.1, J90.2, J99.4, JP1.1 (A), R10.2, R24.1, R25.1, U1.1 (GND), U1.5 (3_LRCLK2), U1.6 (4_BCLK2), U1.34 (GND), U1.47 (GND), U1.52 (GND), U1.58 (GND), U1.59 (GND), U1.64 (GND), U2.3 (GND), U3.5 (GND), U5.9 (GND), U5.19 (GND), U6.2 (GND), U7.2 (GND), U8.6 (INH), U8.7 (GND), U8.8 (GND), UNK1.8 (SCLK/MFP3), UNK1.12 (SPI_SELECT), UNK1.17 (AVSS), UNK1.19 (MICBIAS), UNK1.30 (LDO_SELECT), UNK1.32 (GPIO/MFP5), UNK1.33 (EP); also elsewhere on the board
Board_0-/bottom/GPIO_1: U1.32 (40_A16); also elsewhere on the board
Board_0-/bottom/GPIO_2: U1.33 (41_A17); also elsewhere on the board
Board_0-/bottom/GPIO_3: U1.20 (28_RX7); also elsewhere on the board
Board_0-/bottom/GPIO_4: U1.21 (29_TX7); also elsewhere on the board
Board_0-/bottom/GPIO_5: U1.38 (16_A2_RX4_SCL1); also elsewhere on the board
Board_0-/bottom/GPIO_6: U1.39 (17_A3_TX4_SDA1); also elsewhere on the board
Board_0-/bottom/GPIO_7: U1.16 (24_A10_TX6_SCL2); also elsewhere on the board
Board_0-/bottom/GPIO_8: U1.17 (25_A11_RX6_SDA2); also elsewhere on the board
Board_0-/bottom/GPIO_9: U1.44 (22_A8_CTX1); also elsewhere on the board
Board_0-/bottom/GPIO_10: U1.2 (0_RX1_CRX2_CS1); also elsewhere on the board
Board_0-/bottom/GPIO_11: U1.3 (1_TX1_CTX2_MISO1); also elsewhere on the board
Board_0-/bottom/GPIO_12: U1.13 (11_MOSI_CTX1); also elsewhere on the board
Board_0-/bottom/GPIO_13: U1.28 (36_CS); also elsewhere on the board
Board_0-/bottom/GPIO_14: U1.7 (5_IN2); also elsewhere on the board
Board_0-/bottom/GPIO_15: U1.8 (6_OUT1D); also elsewhere on the board
Board_0-/bottom/GPIO_16: U1.12 (10_CS_MQSR); also elsewhere on the board
Board_0-/bottom/GPIO_BPM: U1.31 (39_MISO1_OUT1A); also elsewhere on the board
Board_0-/bottom/GPIO_FX: U1.19 (27_A13_SCK1); also elsewhere on the board
Board_0-/bottom/GPIO_PLAY: U1.14 (12_MISO_MQSL); also elsewhere on the board
Board_0-/bottom/GPIO_SOUND: U1.29 (37_CS); also elsewhere on the board
Board_0-/bottom/GPIO_SPECIAL: U1.22 (30_CRX3); also elsewhere on the board
Board_0-/bottom/GPIO_WRITE: U1.11 (9_OUT1C); also elsewhere on the board
Board_0-/bottom/HPL: C18.2, J84.3, R25.2
Board_0-/bottom/HPR: C19.2, J84.2, R24.2
Board_0-/bottom/HP_3V3: C22.2, C31.1, U6.5 (OUT), UNK1.26 (LDOIN/HPVDD), UNK1.31 (RESET#)
Board_0-/bottom/H_USB_5V: J70.1 (VBUS), U1.55 (5V)
Board_0-/bottom/H_USB_D+: J70.3 (D+), U1.57 (D+)
Board_0-/bottom/H_USB_D-: J70.2 (D-), U1.56 (D-)
Board_0-/bottom/LOL: C29.2, J83.3, R26.2
Board_0-/bottom/LOR: C28.1, J83.2, R27.2
Board_0-/bottom/MCLK: R15.2, U1.45 (23_A9_CRX1_MCLK1)
Board_0-/bottom/MIDI_1_BUF_OUT: R3.2, U2.4 (Y)
Board_0-/bottom/MIDI_1_IN: R8.2, U1.37 (15_A1_RX3_SPDIF_IN), U3.4 (VO)
Board_0-/bottom/MIDI_1_OUT: U1.36 (14_A0_TX3_SPDIF_OUT), U2.2 (A)
Board_0-/bottom/MIDI_IN_EXT: J99.2, U1.26 (34_RX8), U5.12 (GPIO21/U0TXD)
Board_0-/bottom/MIDI_OUT_EXT: J99.3, U1.27 (35_TX8), U5.11 (GPIO20/U0RXD)
Board_0-/bottom/POT_GAIN_IN: U8.5 (2Y1); also elsewhere on the board
Board_0-/bottom/POT_INPUT_PLAY_MIX: U8.2 (2Y2); also elsewhere on the board
Board_0-/bottom/POT_VOL_OUT: U8.4 (2Y3); also elsewhere on the board
Board_0-/bottom/SCL: R20.2, U1.41 (19_A5_SCL)
Board_0-/bottom/SDA: R21.2, U1.40 (18_A4_SDA)
Board_0-/bottom/SELECT_A: U1.18 (26_A12_MOSI1), U8.10 (A)
Board_0-/bottom/SELECT_B: U1.23 (31_CTX3), U8.9 (B)
Board_0-/bottom/SYNC_OUT: J0.2, U1.24 (32_OUT1B)
Board_0-/bottom/WCLK: R17.2, U1.42 (20_A6_TX5_LRCLK1)
Board_0-Net-(C8-Pad1): C8.1, JP1.2 (B), U5.8 (GPIO9)
Board_0-Net-(C9-Pad1): C9.1, J1.3
Board_0-Net-(C9-Pad2): C9.2, UNK1.13 (IN1_L)
Board_0-Net-(C10-Pad1): C10.1, J1.2
Board_0-Net-(C10-Pad2): C10.2, UNK1.14 (IN1_R)
Board_0-Net-(C11-Pad1): C11.1, J2.3
Board_0-Net-(C11-Pad2): C11.2, UNK1.15 (IN2_L)
Board_0-Net-(C12-Pad1): C12.1, J2.2
Board_0-Net-(C12-Pad2): C12.2, UNK1.16 (IN2_R)
Board_0-Net-(C15-Pad2): C15.2, C33.2, UNK1.18 (REF)
Board_0-Net-(C16-Pad1): C16.1, UNK1.22 (LOL)
Board_0-Net-(C16-Pad2): C16.2, R26.1
Board_0-Net-(C17-Pad1): C17.1, UNK1.23 (LOR)
Board_0-Net-(C17-Pad2): C17.2, R27.1
Board_0-Net-(C18-Pad1): C18.1, R23.2
Board_0-Net-(C19-Pad1): C19.1, R22.2
Board_0-Net-(C32-Pad1): C32.1, C38.1
Board_0-Net-(C34-Pad2): C34.2, C35.2, UNK1.28 (DVSS)
Board_0-Net-(C36-Pad2): C36.2, C37.2, UNK1.7 (IOVSS)
Board_0-Net-(D1-Pad1): D1.1 (K), R7.2, U3.1
Board_0-Net-(D1-Pad2): D1.2 (A), J40.5, J82.2, U3.2
Board_0-Net-(D2-Pad1): D2.1 (K), R10.1
Board_0-Net-(D2-Pad2): D2.2 (A), U1.35 (13_SCK_LED)
Board_0-Net-(J40-Pad4): J40.4, J82.3, R7.1
Board_0-Net-(J81-Pad2): J81.2, J90.5, R3.1
Board_0-Net-(J81-Pad3): J81.3, J90.4, R2.1
Board_0-Net-(R14-Pad1): R14.1, U5.7 (GPIO8)
Board_0-Net-(R15-Pad1): R15.1, UNK1.1 (MCLK)
Board_0-Net-(R16-Pad1): R16.1, UNK1.2 (BCLK)
Board_0-Net-(R17-Pad1): R17.1, UNK1.3 (WCLK)
Board_0-Net-(R18-Pad1): R18.1, UNK1.4 (DIN/MFP1)
Board_0-Net-(R19-Pad1): R19.1, UNK1.5 (DOUT/MFP2)
Board_0-Net-(R20-Pad1): R20.1, UNK1.9 (SCL/SS#)
Board_0-Net-(R21-Pad1): R21.1, UNK1.10 (SDA/MOSI)
Board_0-Net-(R22-Pad1): R22.1, UNK1.27 (HPR)
Board_0-Net-(R23-Pad1): R23.1, UNK1.25 (HPL)
Board_0-unconnected-(J0-Pad3): J0.3
Board_0-unconnected-(J40-Pad1): J40.1
Board_0-unconnected-(J40-Pad2): J40.2
Board_0-unconnected-(J40-Pad3): J40.3
Board_0-unconnected-(J90-Pad1): J90.1
Board_0-unconnected-(J90-Pad3): J90.3
Board_0-unconnected-(U1-Pad49): U1.49 (VUSB)
Board_0-unconnected-(U2-Pad1): U2.1 (NC)
Board_0-unconnected-(U3-Pad3): U3.3 (NC)
Board_0-unconnected-(U5-Pad3): U5.3 (GPIO4/ADC1_CH4)
Board_0-unconnected-(U5-Pad4): U5.4 (GPIO5/ADC2_CH0)
Board_0-unconnected-(U5-Pad5): U5.5 (GPIO6)
Board_0-unconnected-(U5-Pad6): U5.6 (GPIO7)
Board_0-unconnected-(U5-Pad10): U5.10 (GPIO10)
Board_0-unconnected-(U5-Pad13): U5.13 (GPIO18/USB_D-)
Board_0-unconnected-(U5-Pad14): U5.14 (GPIO19/USB_D+)
Board_0-unconnected-(U5-Pad15): U5.15 (GPIO3/ADC1_CH3)
Board_0-unconnected-(U5-Pad16): U5.16 (GPIO2/ADC1_CH2)
Board_0-unconnected-(U5-Pad17): U5.17 (GPIO1/ADC1_CH1/XTAL_32K_N)
Board_0-unconnected-(U5-Pad18): U5.18 (GPIO0/ADC1_CH0/XTAL_32K_P)
Board_0-unconnected-(U6-Pad4): U6.4 (NC)
Board_0-unconnected-(U7-Pad4): U7.4 (NC)
Board_0-unconnected-(U8-Pad1): U8.1 (2Y0)
Board_0-unconnected-(U8-Pad11): U8.11 (1Y3)
Board_0-unconnected-(U8-Pad12): U8.12 (1Y0)
Board_0-unconnected-(U8-Pad13): U8.13 (1-COM)
Board_0-unconnected-(U8-Pad14): U8.14 (1Y1)
Board_0-unconnected-(U8-Pad15): U8.15 (1Y2)
Board_0-unconnected-(UNK1-Pad11): UNK1.11 (MISO/MFP4)
Board_0-unconnected-(UNK1-Pad20): UNK1.20 (IN3_L)
Board_0-unconnected-(UNK1-Pad21): UNK1.21 (IN3_R)

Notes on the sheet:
MIDI OUT
ESP32
MIDI IN
TEENSY 4.1

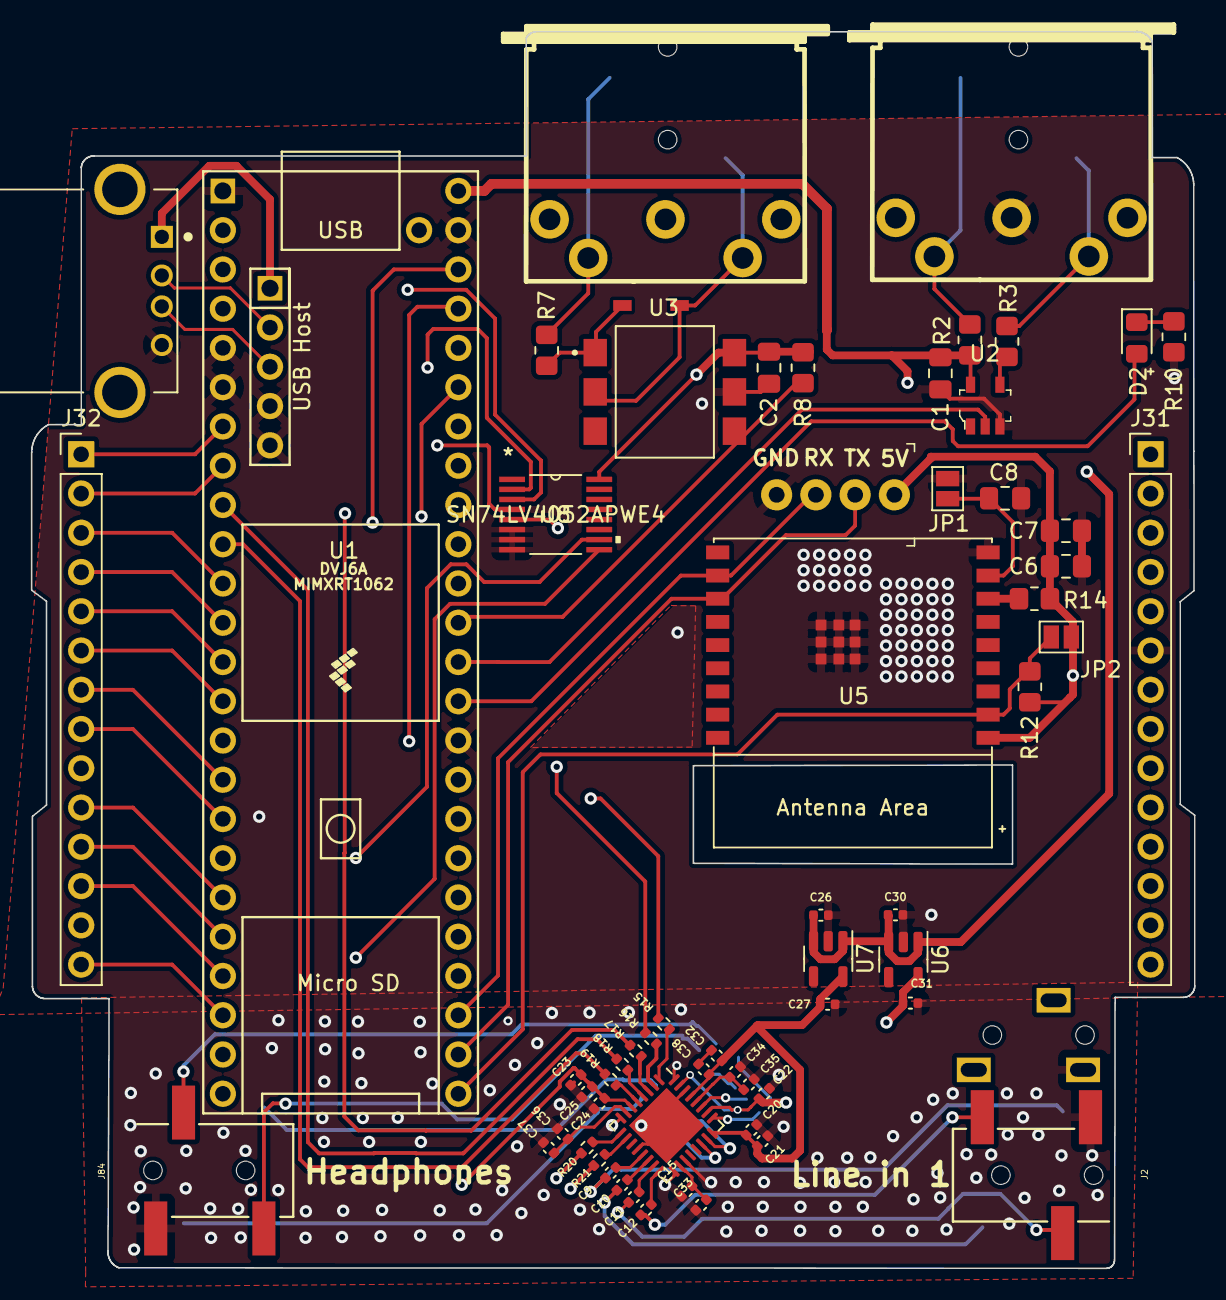
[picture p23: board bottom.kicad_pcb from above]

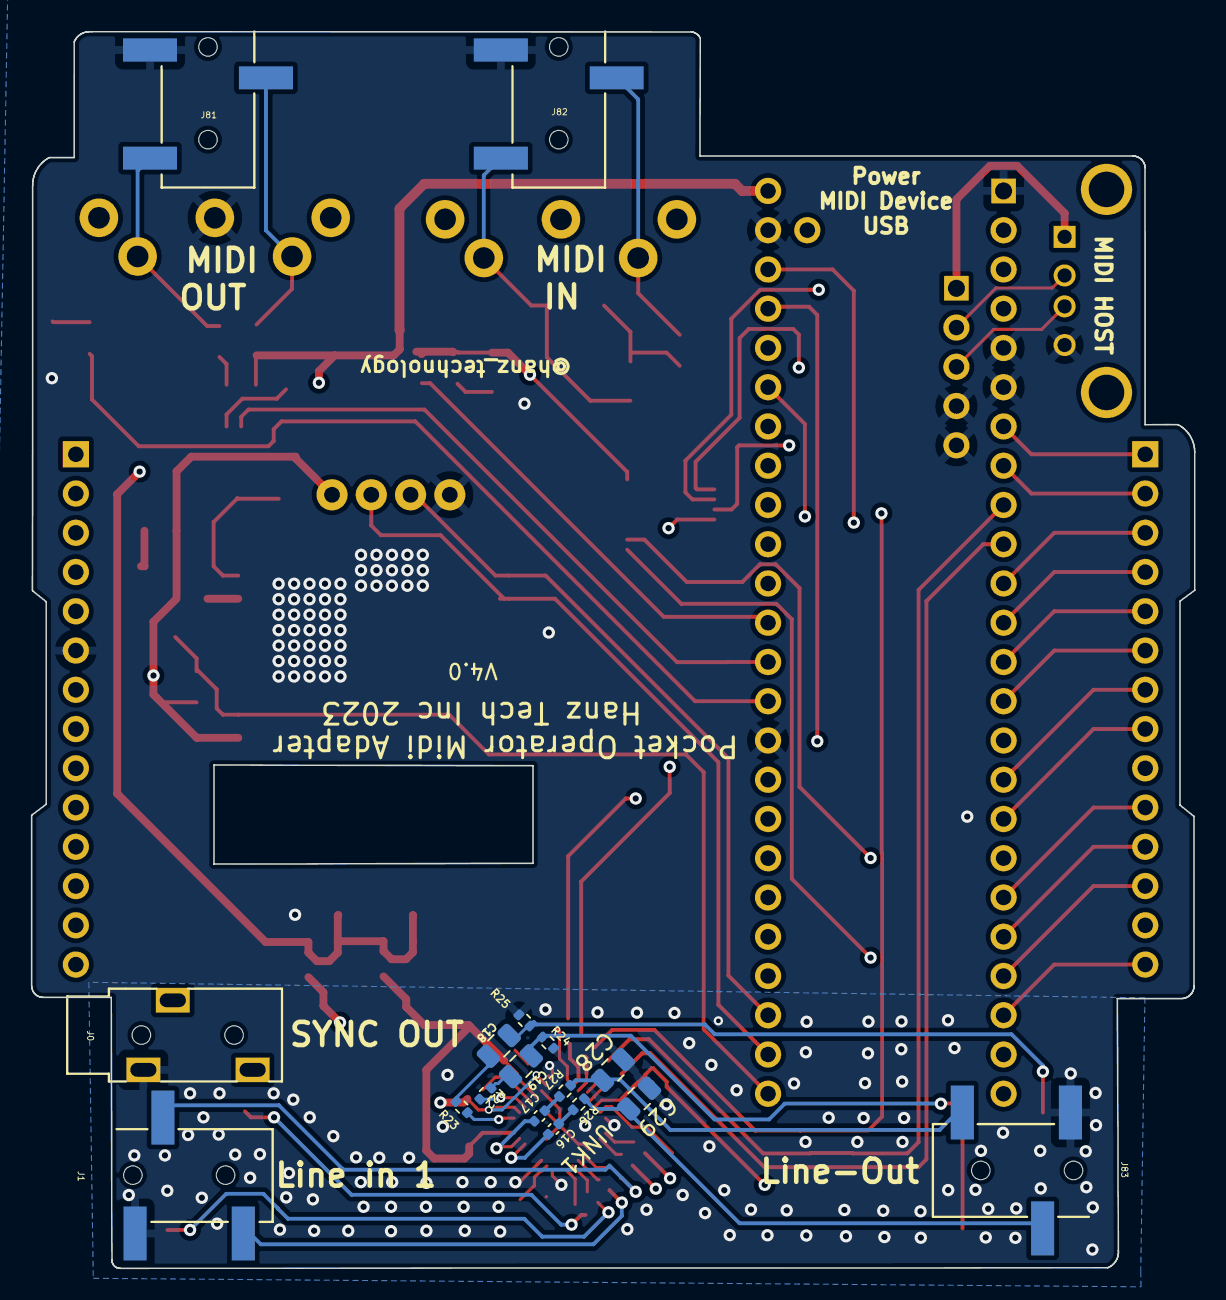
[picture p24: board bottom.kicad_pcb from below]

Board: 4 copper layers, 75.3 x 80.0 mm, 78 parts (17 on the bottom side), 91 nets.

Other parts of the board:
J31, J32: Conn_01x14_Female; PinHeader_1x14_P2.54mm_Vertical

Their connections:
Board_0-/bottom/3.3V: J31.5; also elsewhere on the board
Board_0-/bottom/GIPO_PATTERN: J31.12; also elsewhere on the board
Board_0-/bottom/GND: J31.6; also elsewhere on the board
Board_0-/bottom/GPIO_1: J31.10; also elsewhere on the board
Board_0-/bottom/GPIO_2: J31.9; also elsewhere on the board
Board_0-/bottom/GPIO_3: J32.11; also elsewhere on the board
Board_0-/bottom/GPIO_4: J32.12; also elsewhere on the board
Board_0-/bottom/GPIO_5: J31.8; also elsewhere on the board
Board_0-/bottom/GPIO_6: J31.7; also elsewhere on the board
Board_0-/bottom/GPIO_7: J32.7; also elsewhere on the board
Board_0-/bottom/GPIO_8: J32.8; also elsewhere on the board
Board_0-/bottom/GPIO_9: J31.3; also elsewhere on the board
Board_0-/bottom/GPIO_10: J31.1; also elsewhere on the board
Board_0-/bottom/GPIO_11: J31.2; also elsewhere on the board
Board_0-/bottom/GPIO_12: J32.5; also elsewhere on the board
Board_0-/bottom/GPIO_13: J31.14; also elsewhere on the board
Board_0-/bottom/GPIO_14: J32.1; also elsewhere on the board
Board_0-/bottom/GPIO_15: J32.2; also elsewhere on the board
Board_0-/bottom/GPIO_16: J32.4; also elsewhere on the board
Board_0-/bottom/GPIO_BPM: J31.11; also elsewhere on the board
Board_0-/bottom/GPIO_FX: J32.10; also elsewhere on the board
Board_0-/bottom/GPIO_PLAY: J32.6; also elsewhere on the board
Board_0-/bottom/GPIO_SOUND: J31.13; also elsewhere on the board
Board_0-/bottom/GPIO_SPECIAL: J32.14; also elsewhere on the board
Board_0-/bottom/GPIO_WRITE: J32.3; also elsewhere on the board
Board_0-/bottom/POT_GAIN_IN: J31.4; also elsewhere on the board
Board_0-/bottom/POT_INPUT_PLAY_MIX: J32.9; also elsewhere on the board
Board_0-/bottom/POT_VOL_OUT: J32.13; also elsewhere on the board

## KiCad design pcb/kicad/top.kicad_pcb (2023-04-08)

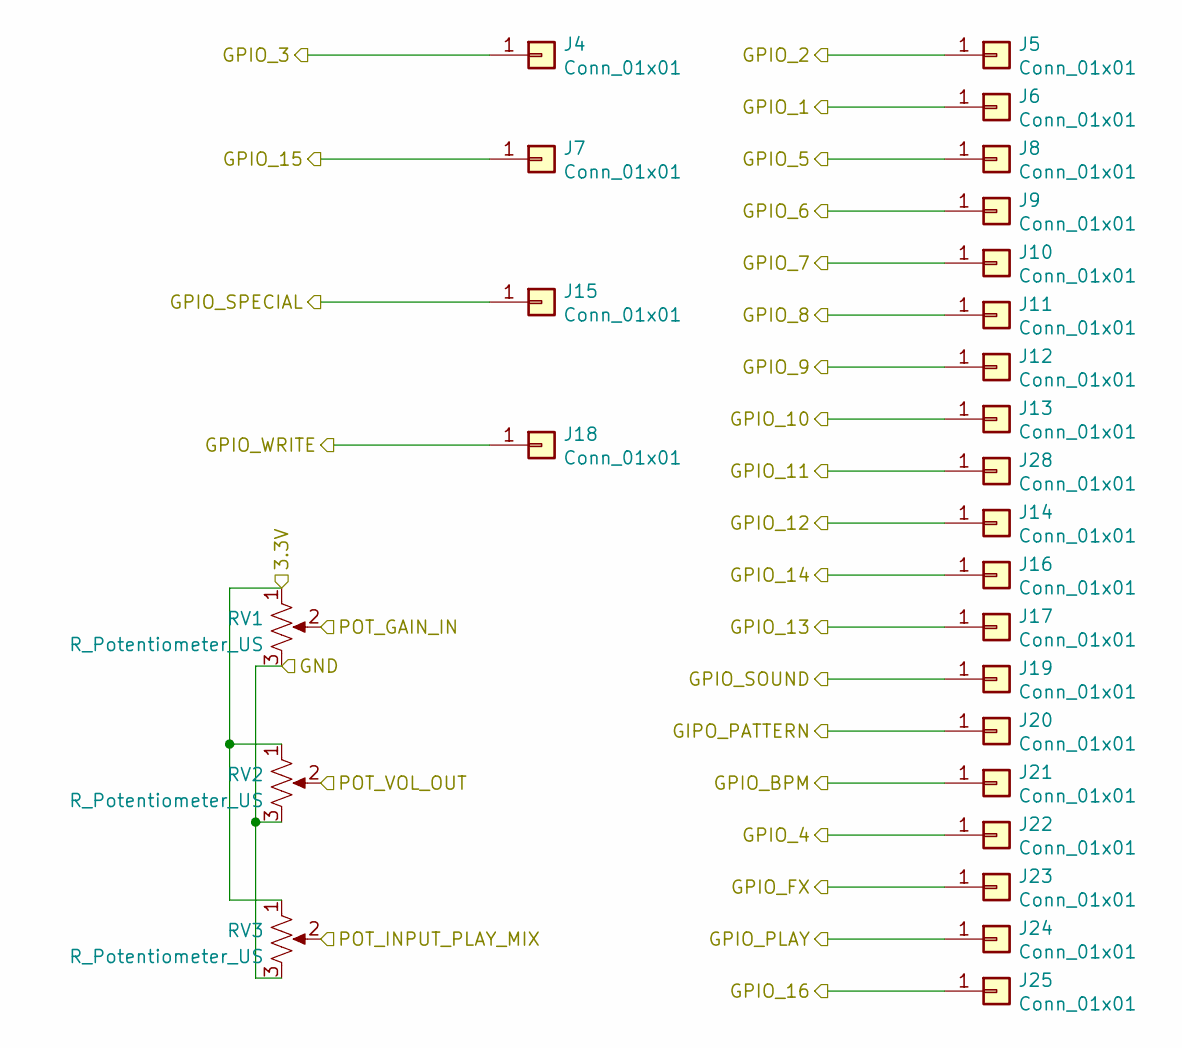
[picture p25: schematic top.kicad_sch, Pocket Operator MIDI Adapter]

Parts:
J4, J5, J6, J7, J8, J9, J10, J11, J12, J13, J14, J15, J16, J17, J18, J19, J20, J21, J22, J23, J24, J25, J28: Conn_01x01; Pin_D1.0mm_L10.0mm
RV1, RV2, RV3: R_Potentiometer_US; RES-ADJ-TH_RK09Y11L0001; LCSC C470717

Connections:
Board_0-/top/3.3V: RV1.1, RV2.1, RV3.1; also elsewhere on the board
Board_0-/top/GIPO_PATTERN: J20.1; also elsewhere on the board
Board_0-/top/GND: RV1.3, RV2.3, RV3.3; also elsewhere on the board
Board_0-/top/GPIO_1: J6.1; also elsewhere on the board
Board_0-/top/GPIO_2: J5.1; also elsewhere on the board
Board_0-/top/GPIO_3: J4.1; also elsewhere on the board
Board_0-/top/GPIO_4: J22.1; also elsewhere on the board
Board_0-/top/GPIO_5: J8.1; also elsewhere on the board
Board_0-/top/GPIO_6: J9.1; also elsewhere on the board
Board_0-/top/GPIO_7: J10.1; also elsewhere on the board
Board_0-/top/GPIO_8: J11.1; also elsewhere on the board
Board_0-/top/GPIO_9: J12.1; also elsewhere on the board
Board_0-/top/GPIO_10: J13.1; also elsewhere on the board
Board_0-/top/GPIO_11: J28.1; also elsewhere on the board
Board_0-/top/GPIO_12: J14.1; also elsewhere on the board
Board_0-/top/GPIO_13: J17.1; also elsewhere on the board
Board_0-/top/GPIO_14: J16.1; also elsewhere on the board
Board_0-/top/GPIO_15: J7.1; also elsewhere on the board
Board_0-/top/GPIO_16: J25.1; also elsewhere on the board
Board_0-/top/GPIO_BPM: J21.1; also elsewhere on the board
Board_0-/top/GPIO_FX: J23.1; also elsewhere on the board
Board_0-/top/GPIO_PLAY: J24.1; also elsewhere on the board
Board_0-/top/GPIO_SOUND: J19.1; also elsewhere on the board
Board_0-/top/GPIO_SPECIAL: J15.1; also elsewhere on the board
Board_0-/top/GPIO_WRITE: J18.1; also elsewhere on the board
Board_0-/top/POT_GAIN_IN: RV1.2; also elsewhere on the board
Board_0-/top/POT_INPUT_PLAY_MIX: RV3.2; also elsewhere on the board
Board_0-/top/POT_VOL_OUT: RV2.2; also elsewhere on the board

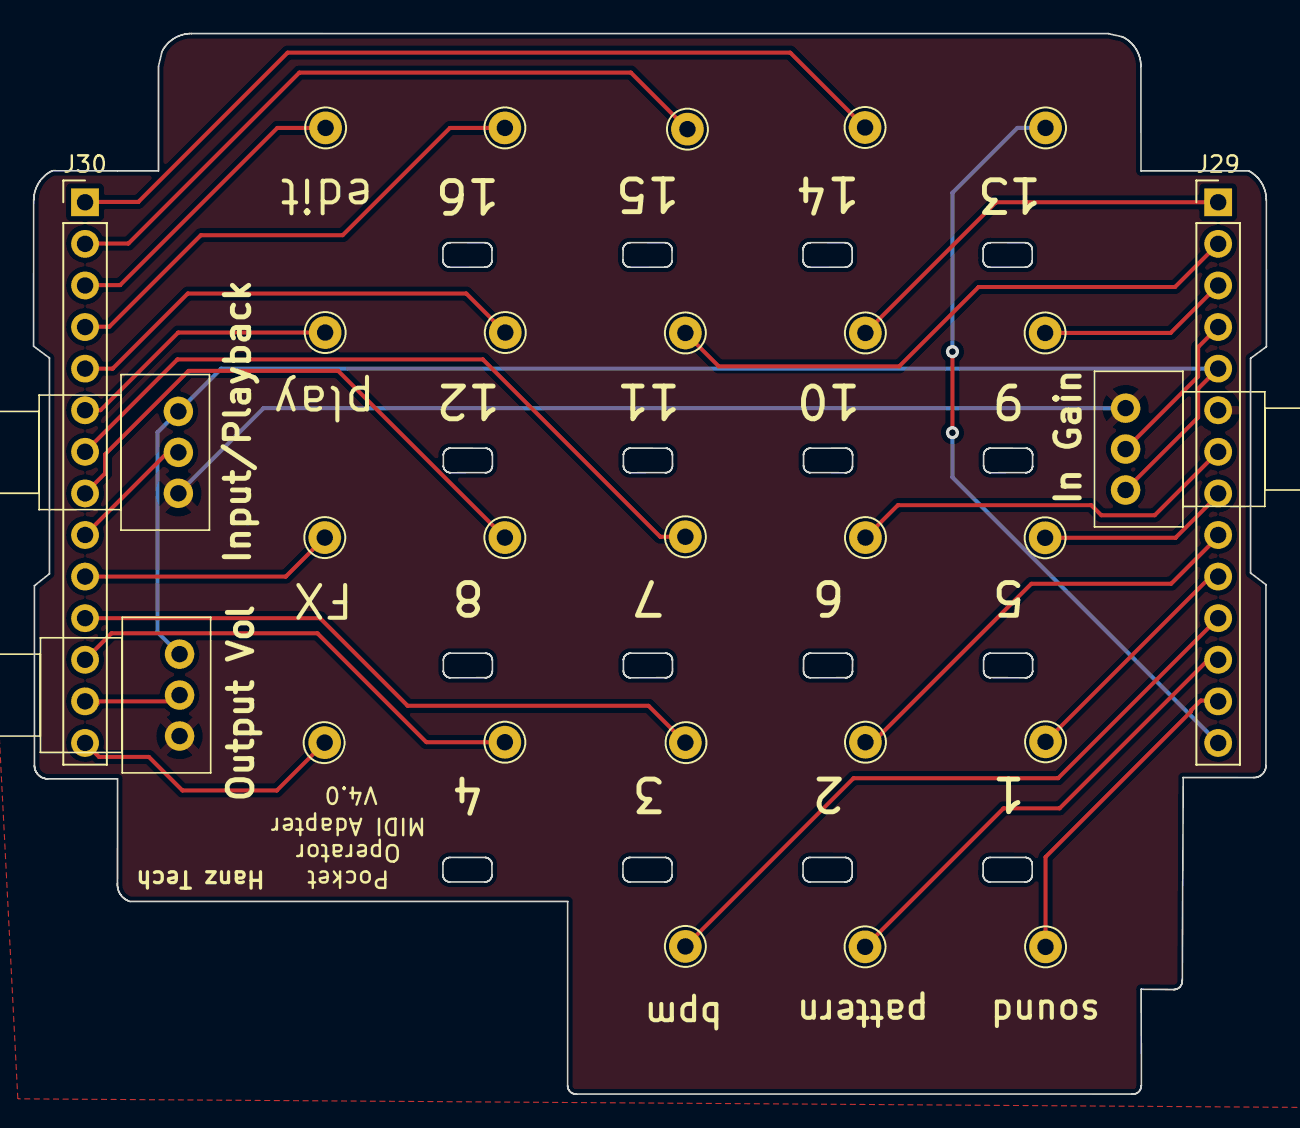
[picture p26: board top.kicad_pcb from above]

Board: 2 copper layers, 75.3 x 64.8 mm, 28 parts (0 on the bottom side), 28 nets.

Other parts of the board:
J29, J30: Conn_01x14_Male; PinHeader_1x14_P2.54mm_Vertical

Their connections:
Board_0-/top/3.3V: J29.5; also elsewhere on the board
Board_0-/top/GIPO_PATTERN: J29.12; also elsewhere on the board
Board_0-/top/GND: J29.6; also elsewhere on the board
Board_0-/top/GPIO_1: J29.10; also elsewhere on the board
Board_0-/top/GPIO_2: J29.9; also elsewhere on the board
Board_0-/top/GPIO_3: J30.11; also elsewhere on the board
Board_0-/top/GPIO_4: J30.12; also elsewhere on the board
Board_0-/top/GPIO_5: J29.8; also elsewhere on the board
Board_0-/top/GPIO_6: J29.7; also elsewhere on the board
Board_0-/top/GPIO_7: J30.7; also elsewhere on the board
Board_0-/top/GPIO_8: J30.8; also elsewhere on the board
Board_0-/top/GPIO_9: J29.3; also elsewhere on the board
Board_0-/top/GPIO_10: J29.1; also elsewhere on the board
Board_0-/top/GPIO_11: J29.2; also elsewhere on the board
Board_0-/top/GPIO_12: J30.5; also elsewhere on the board
Board_0-/top/GPIO_13: J29.14; also elsewhere on the board
Board_0-/top/GPIO_14: J30.1; also elsewhere on the board
Board_0-/top/GPIO_15: J30.2; also elsewhere on the board
Board_0-/top/GPIO_16: J30.4; also elsewhere on the board
Board_0-/top/GPIO_BPM: J29.11; also elsewhere on the board
Board_0-/top/GPIO_FX: J30.10; also elsewhere on the board
Board_0-/top/GPIO_PLAY: J30.6; also elsewhere on the board
Board_0-/top/GPIO_SOUND: J29.13; also elsewhere on the board
Board_0-/top/GPIO_SPECIAL: J30.14; also elsewhere on the board
Board_0-/top/GPIO_WRITE: J30.3; also elsewhere on the board
Board_0-/top/POT_GAIN_IN: J29.4; also elsewhere on the board
Board_0-/top/POT_INPUT_PLAY_MIX: J30.9; also elsewhere on the board
Board_0-/top/POT_VOL_OUT: J30.13; also elsewhere on the board

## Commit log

2021-10-23 split to top and bottom board
    [CUI_DEVICES_SDF-50J.step, audio_jack v2.step, button.3mf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]
2021-12-05 switched to hierarchical design
    [CUI_DEVICES_SDF-50J.step, audio_jack v2.step, bottom.kicad_pcb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]
2021-12-06 update board with logo
    [po_midi_adapter.kicad_pcb]
2021-12-09 Added esp32 c3 for MIDI BLE
    [ESP32-WROOM-32D.step, bottom.kicad_pcb, bottom.sch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]
2021-12-12 fixed bottom board LDO footprint
    [bottom-B_Cu.gbr, bottom-B_Mask.gbr, bottom-B_Paste.gbr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]
2021-12-22 updated bom, removed old photo, added render
    [base.3mf, base_top.3mf, bottom.sch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]
2022-01-05 fixed power supply footprint
    [bottom.sch, po_midi_adapter.kicad_pcb, po_midi_adapter.sch]
2022-01-11 fixed strapping pin 8
    [bottom.sch, po_midi_adapter.kicad_pcb, po_midi_adapter.sch]
2022-01-11 version bump to 3.1
    [base.3mf, base_top.3mf, bottom.kicad_pcb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]
2022-01-20 bump to v3.1, upgrade to kicad v6
    [bottom-B_Cu.gbr, bottom-B_Mask.gbr, bottom-B_Paste.gbr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]
2022-02-23 v3.2 : added midi trs, connected ESP32 EN pin to Teensy
    [bottom-B_Cu.gbr, bottom-B_Mask.gbr, bottom-B_Paste.gbr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]
2022-03-06 update to version 3.3, include trs midi, esp32-enable pin
    [bottom-B_Cu.gbr, bottom-B_Mask.gbr, bottom-B_Paste.gbr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]
2022-05-29 update to 3.4, ready for production
    [bottom-B_Cu.gbr, bottom-B_Mask.gbr, bottom-B_Paste.gbr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]
2022-06-17 cleanup 3d models
    [1set_complete.3mf, esp32_cover.3mf, optoisolator_cover.3mf]
2023-01-10 added new codec chip tlc320aic3204
    [PO CAD_empty v1.dxf, bottom.kicad_sch, po_midi_adapter.kicad_pcb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]
2023-01-11 shifting pins
    [bottom.kicad_sch, po_midi_adapter.kicad_sch, top.kicad_sch]
2023-01-12 fixed routing for esp32
    [bottom.kicad_sch, po_midi_adapter.kicad_pcb, po_midi_adapter.kicad_sch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]
2023-01-13 started codec placement
    [po_midi_adapter.kicad_pcb]
2023-01-16 codec layout
    [bottom.kicad_sch, po_midi_adapter.kicad_pcb]
2023-02-01 update bottom board
    [bottom.kicad_sch, po_midi_adapter.kicad_pcb, po_midi_adapter.kicad_sch]
2023-02-02 update board
    [po_midi_adapter.kicad_pcb, po_midi_adapter.kicad_sch]
2023-02-04 add multiplexer
    [bottom.kicad_sch, po_midi_adapter.kicad_pcb, po_midi_adapter.kicad_sch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]
2023-02-04 finished routing
    [bottom.kicad_sch, po_midi_adapter.kicad_pcb]
2023-02-04 Fix DRC errors
    [po_midi_adapter.kicad_pcb]
2023-02-04 add missing jack
    [po_midi_adapter.kicad_pcb, po_midi_adapter.kicad_sch, top.kicad_sch]
2023-02-04 small cleanup
    [po_midi_adapter.kicad_pcb]
2023-02-07 submitted order 4.0
    [T-1Y18W321477A-2sets-bottom_bom(2023-02-07).xls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]
2023-02-07 Remove old csv
    [bottom_bom.csv, bottom_bom.xls]
2023-04-08 final version 4.0
    [T-1Y18W321477A-2sets-bottom_bom(2023-02-07).xls, T-1Y20W321477A-2sets-T-1Y18W321477A-2sets-bottom_bom(2023-02-07)(2023-02-08).xls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]

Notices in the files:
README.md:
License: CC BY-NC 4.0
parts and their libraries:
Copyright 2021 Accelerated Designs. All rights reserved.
